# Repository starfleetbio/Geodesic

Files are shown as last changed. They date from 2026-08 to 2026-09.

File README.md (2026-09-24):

# Magnetic Geodesic Dome — Scale Model

A 3D-printed, magnet-assembled scale model of a geodesic dome (Montreal Biosphère–inspired),
built as a proof-of-concept for an eventual larger structure. The rest of this page is the
build spec; first, the short version of how it comes together.

<p align="center">
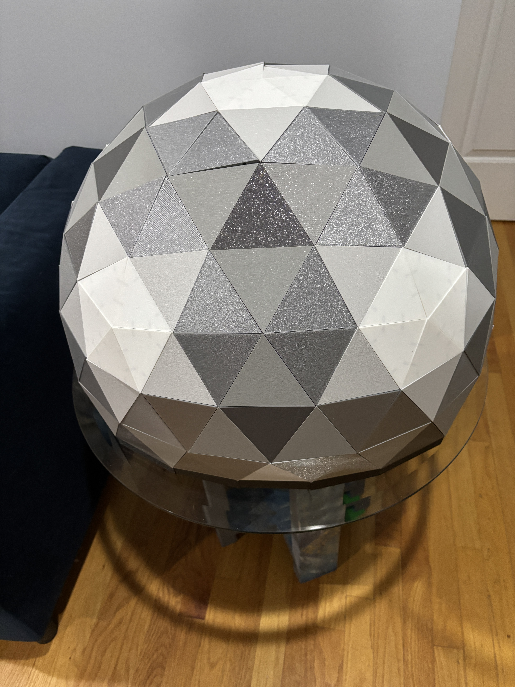
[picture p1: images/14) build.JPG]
The finished dome — 200 panels on a black arc rim, grey ramp from light vertices to dark face centers
  
  <br><em>The built dome — 200 panels seated on the 20-piece black arc rim, greys running light at the vertices to dark at the face centers.</em>
</p>

## From a sphere to a dome you can hold

Geodesic domes turn a sphere into a lattice of triangles — the geometry behind landmarks like Montreal's
**Biosphère** and EPCOT's **Spaceship Earth**, and the starting point for this model.
(Background: [Geodesic polyhedron — Wikipedia](https://en.wikipedia.org/wiki/Geodesic_polyhedron).)

<p align="center">
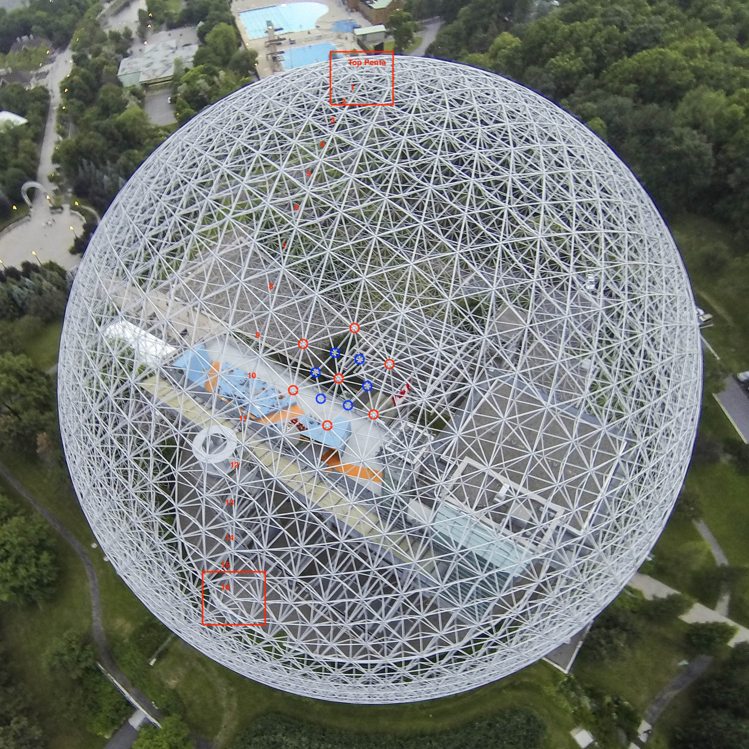
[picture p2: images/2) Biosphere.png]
Montreal Biosphère
  
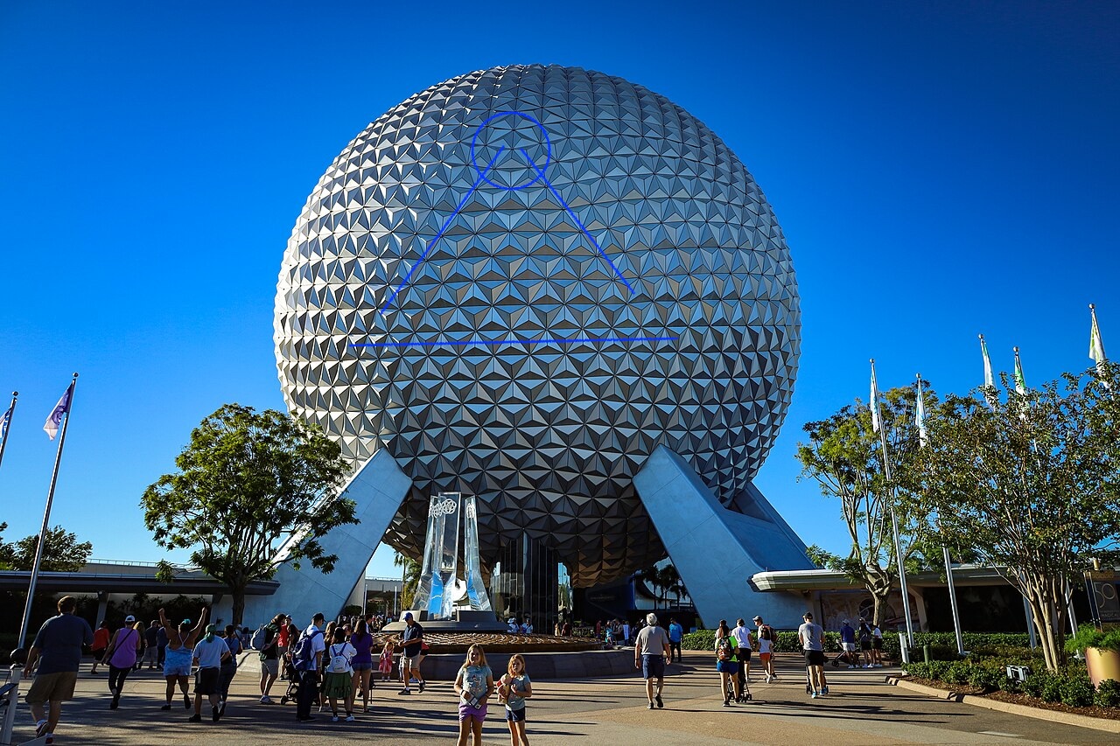
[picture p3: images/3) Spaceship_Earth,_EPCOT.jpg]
Spaceship Earth, EPCOT
  
</p>

<p align="center">
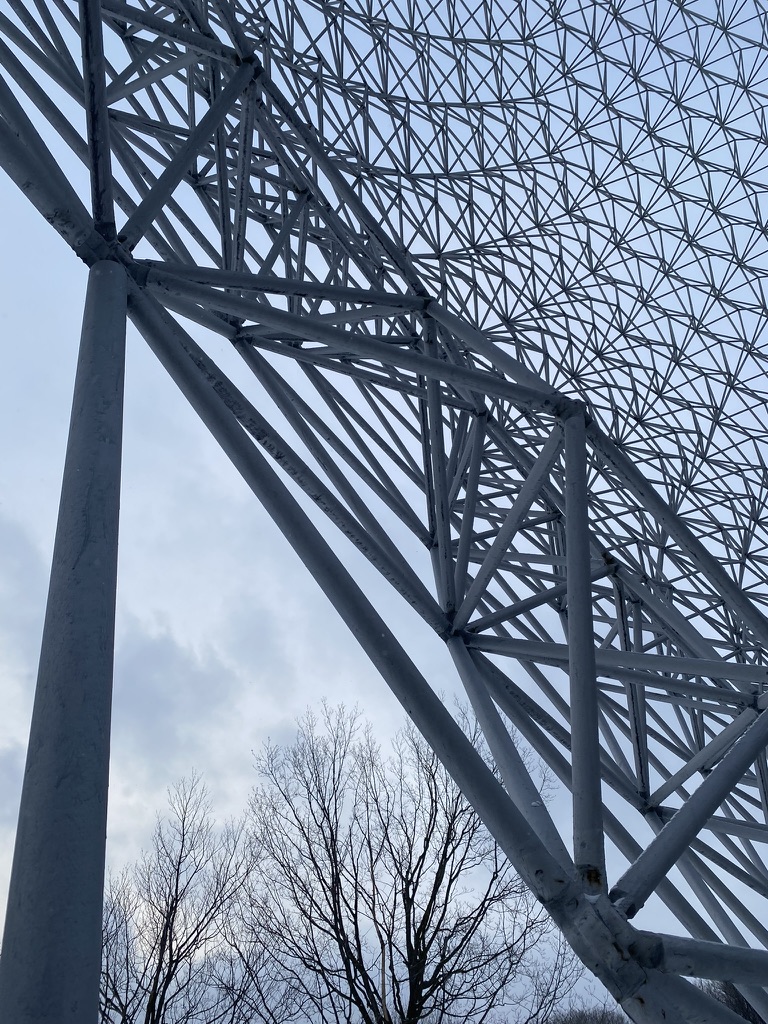
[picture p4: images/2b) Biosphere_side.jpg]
Side view of the Montreal Biosphère geodesic frame
  
  <br><em>A side view of the Montreal Biosphère — the geodesic frame up close.</em>
</p>

Start with an icosahedron and subdivide each of its 20 triangular faces into a finer grid — here **4V**
(four divisions per edge), giving 16 small triangles per face in just five distinct shapes.

<p align="center">
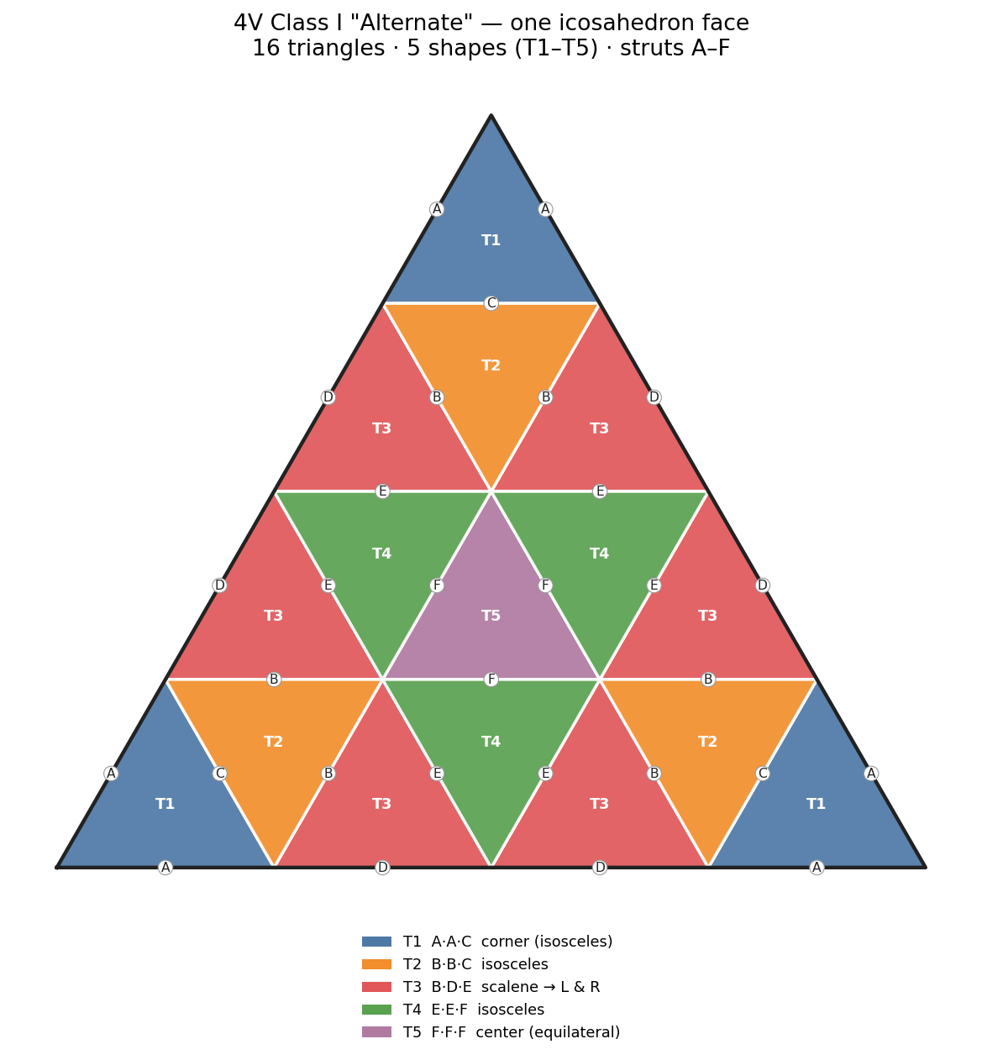
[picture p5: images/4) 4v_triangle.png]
One face subdivided 4V into 16 triangles, shapes T1–T5
  
</p>

Do that to all 20 faces and the whole sphere unfolds into this net:

<p align="center">
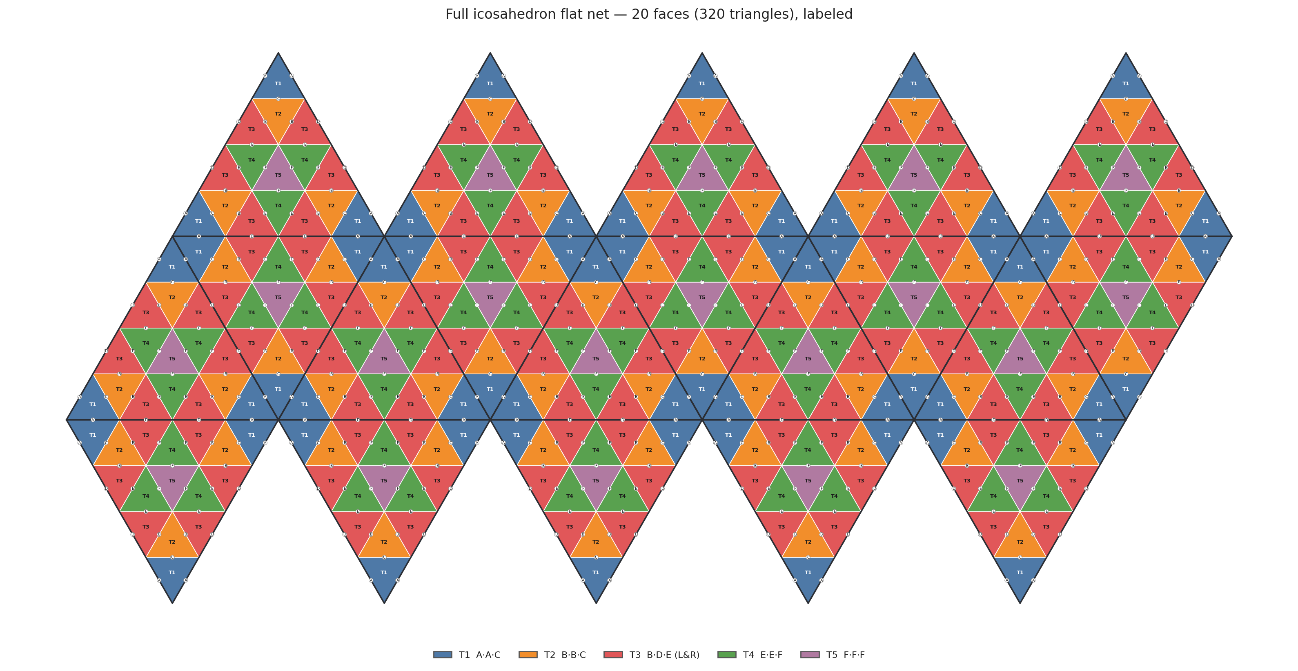
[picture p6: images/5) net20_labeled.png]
Full icosahedron flat net — all 20 faces
  
</p>

A full sphere isn't a dome, though — you cut it. Different fractions give different domes:

<p align="center">
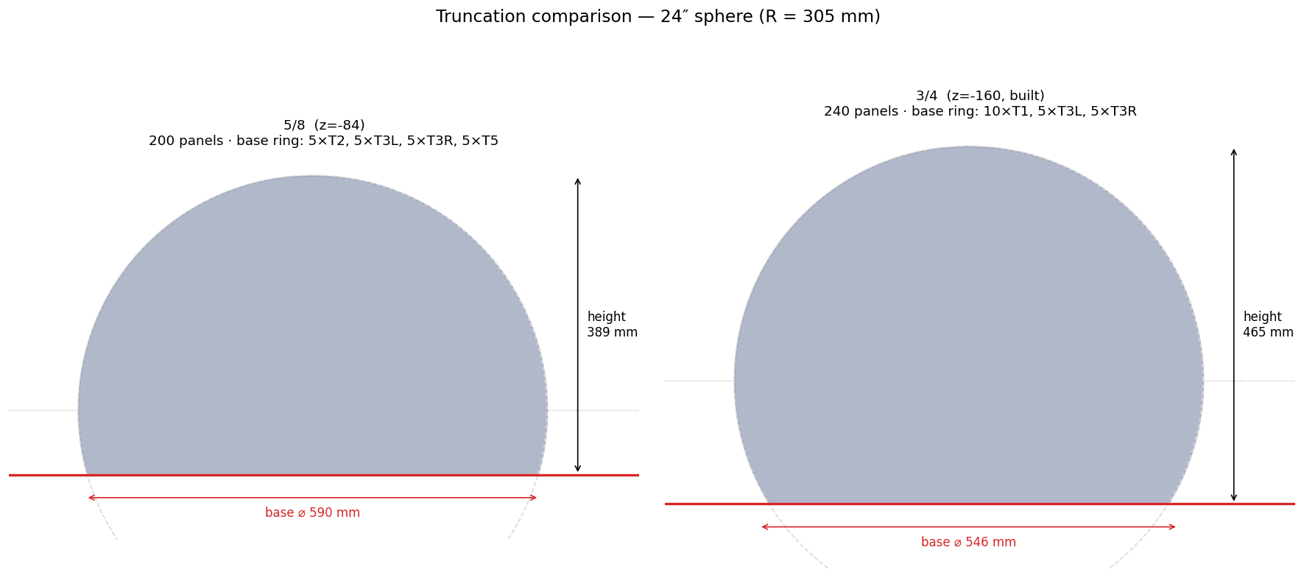
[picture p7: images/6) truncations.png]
Truncation options for the sphere
  
</p>

This model takes the **5/8** cut — everything above a plane just below the equator. That leaves **200
panels**: the actual dome, unfolded (inside view) and colored by shape:

<p align="center">
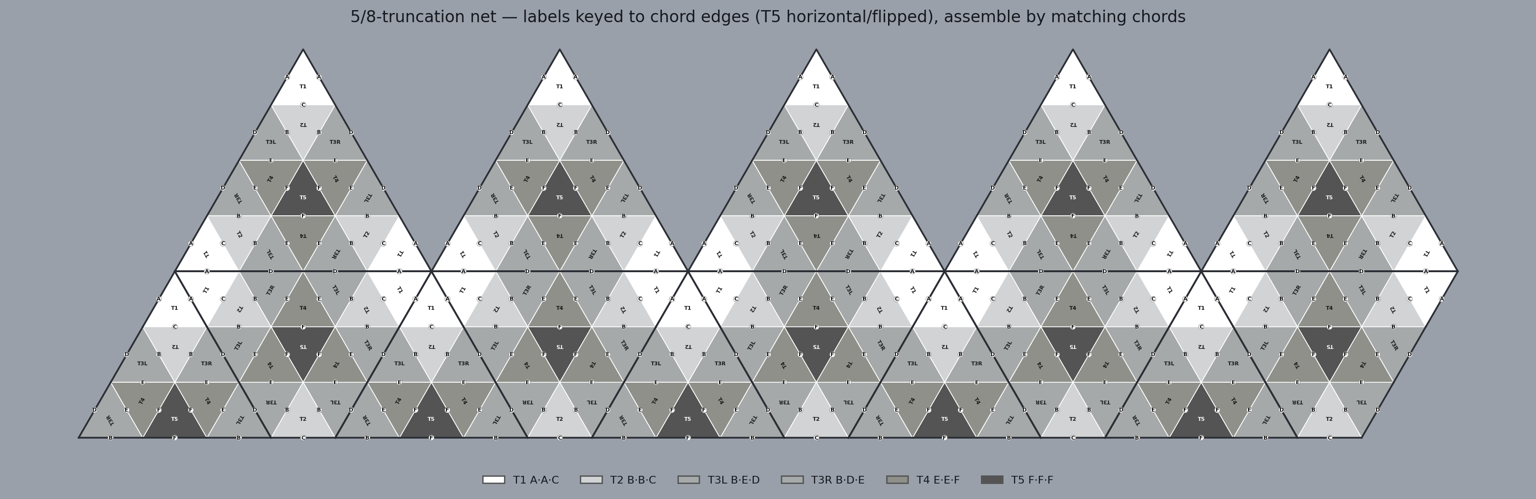
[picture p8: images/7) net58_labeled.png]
5/8-truncation flat net — 200 panels
  
</p>

Those 200 panels reduce to just **six printable parts** (T3 is chiral, so left and right):

<p align="center">
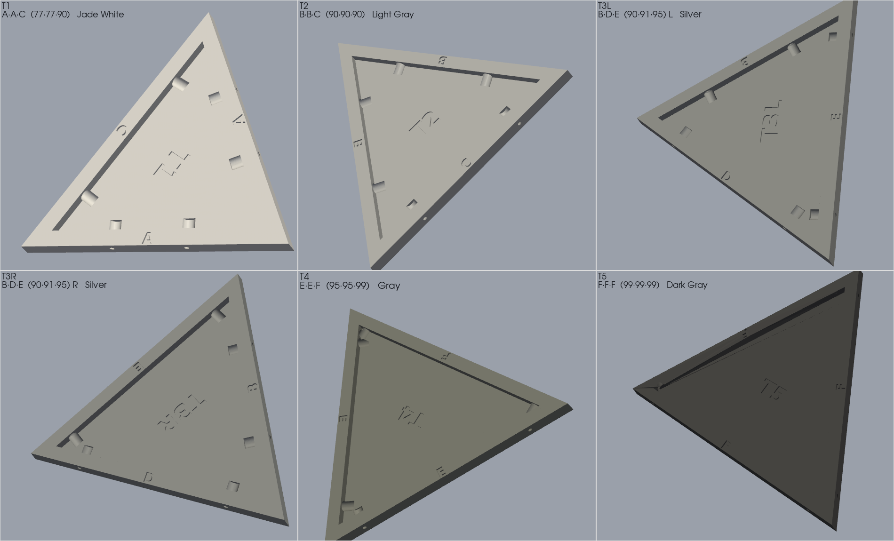
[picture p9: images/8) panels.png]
The six panel shapes, inner face up with labels
  
</p>

Give each shape its own grey — light at the vertices, dark at the centers — and the finished dome reads its
own structure, floating on a black base ring:

<p align="center">
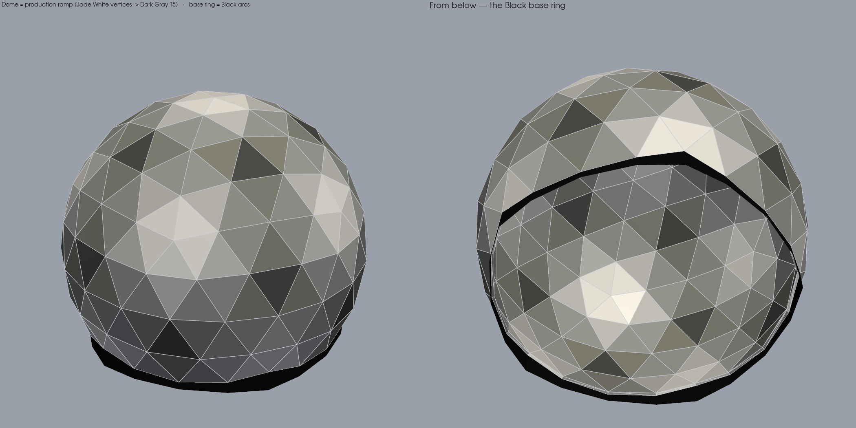
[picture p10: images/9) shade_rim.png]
Dome rendered in the production color ramp
  
</p>

That base is **20 pieces in 4 shapes** T3R(B), T5(F), T3L(B), T2(C) that mitre together into the rim — read them as several arcs or as one continuous ring:

<p align="center">
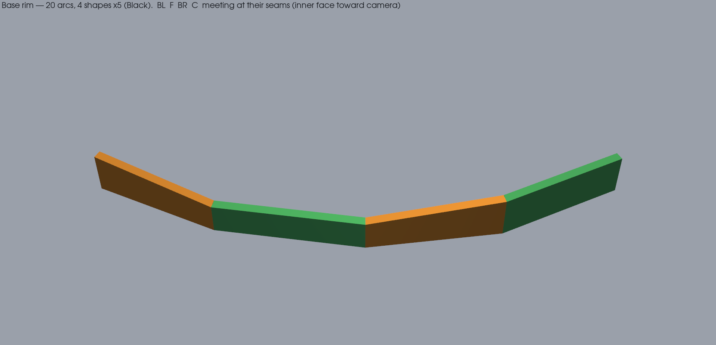
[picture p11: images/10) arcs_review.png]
The four rim arc shapes in black
  
</p>

Everything holds together with **magnets, not glue**. Each edge is *keyed* — its magnet pair sits at a
spacing unique to that chord — so only the correct panels can mate:

<p align="center">
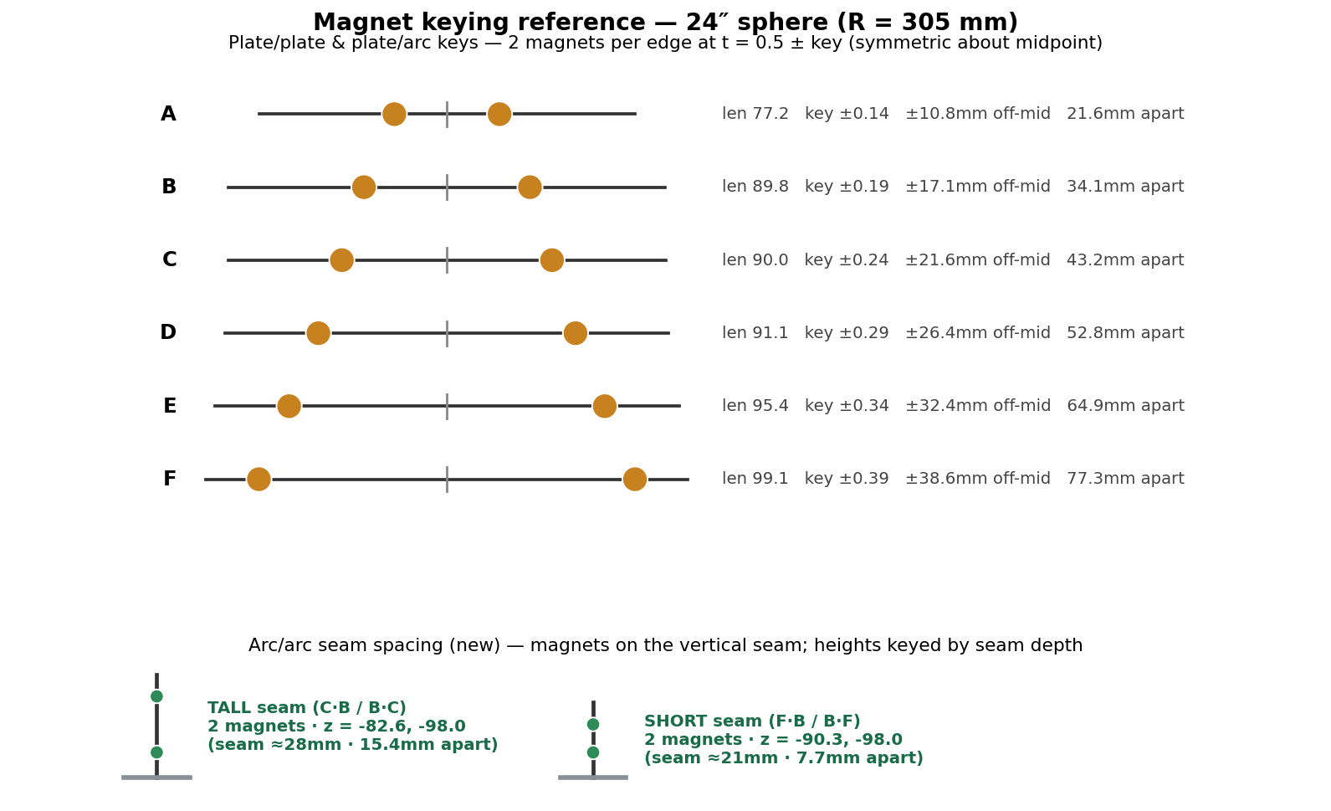
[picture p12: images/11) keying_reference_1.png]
Magnet keying reference
  
</p>

And every magnet lives in the same little channel: a spherical seat that holds the ball flush at the surface,
a short throat that captures it, and a slide to load it from behind with a tamper:

<p align="center">
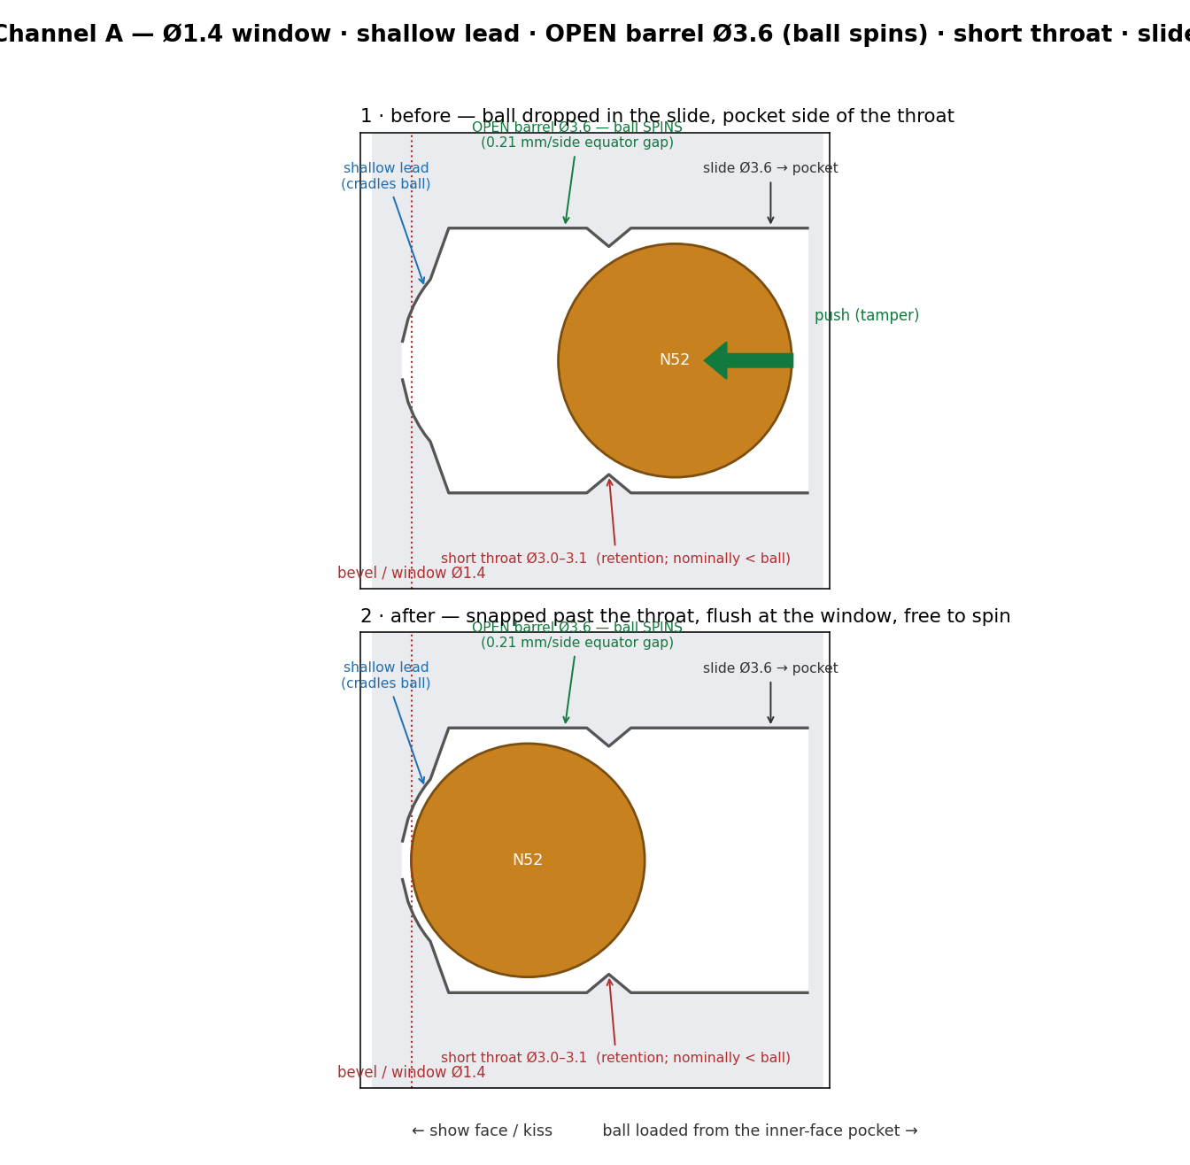
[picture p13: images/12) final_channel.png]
Magnet channel cross-section
  
</p>

---

# Spec sheet

*Rev. after first test print: tapered channel (prints open), show-face-flush orientation (no tilt),
thicker arc walls, bigger/deeper labels. See "First-print revisions" at the end.*

---

## Geometry

| | |
|---|---|
| Solid | Icosahedron |
| Subdivision | **4V (frequency 4)**, **Class I, Method 1** ("alternate") |
| Sphere diameter | **24 in (610 mm)** — radius R = 305 mm |
| Truncation | **5/8** (vertex-up, cut just below the equator at z ≈ −84 mm) |
| Dome height | ≈ 389 mm |
| Base diameter | ≈ 590 mm (a 20-sided zig-zag, amplitude only 7.7 mm) |

The base chord cycle repeats **C · B · F · B** (panels **T2 · T3 · T5 · T3**) five times around.

---

## Panels — 200 total, 6 printable shapes

| Shape | Chords | Edge lengths (mm) | Count |
|---|---|---|---|
| **T1** | A·A·C | 77.2 · 77.2 · 90.0 | 30 |
| **T2** | B·B·C | 89.8 · 89.8 · 90.0 | 35 |
| **T3-L** | D·B·E | 91.1 · 89.8 · 95.4 | 40 |
| **T3-R** | B·D·E | 89.8 · 91.1 · 95.4 | 40 |
| **T4** | E·E·F | 95.4 · 95.4 · 99.1 | 40 |
| **T5** | F·F·F | 99.1 · 99.1 · 99.1 | 15 |

Chord factors → mm (× R = 305): **A 77.2 · B 89.8 · C 90.0 · D 91.1 · E 95.4 · F 99.1**

Each panel: thin central **web 2.2 mm**, thicker **magnet rim 5.2 mm**, edges beveled along the
sphere's radial rays so they close into a sphere. Printed **outer-face-down** for a glossy exterior.

---

## Part labels (debossed on the inner face)

So panels can be sorted and oriented at assembly, each carries ID marks **debossed 0.6 mm into the
inner (pocket) face** — hidden on the finished dome, and facing up during printing so they engrave
cleanly with no supports. The outer show face is untouched.

- **Shape name** (T1 / T2 / T3L / T3R / T4 / T5) centered on the web, upright along the longest edge.
- **Chord letter** (A–F) centered on the rim band beside each edge, so the mating chord is obvious.
- **Arcs** carry their two seat chords: the T2·T3 arc reads **C** and **B**; the T5·T3 arc reads **F** and **B**.

---

## Rim — 20 arcs, 4 printable shapes  *(redesigned: arcs are now built as panels)*

The base ring was reworked so the arcs are **constructed and printed exactly like the triangular panels** —
flat, show-face-down, with the identical channel A loaded from the inner face. This replaced the old two-edge
arcs that printed standing up and whose magnets could not be inserted at all. Each old arc is split at its
middle vertex into two single-chord pieces, giving **20 arcs in 4 unique shapes, 5 each**:

- **C** — top chord C (seats a **T2**); two *tall* seams (symmetric)
- **F** — top chord F (seats a **T5**); two *short* seams (symmetric)
- **BL / BR** — top chord B (seats a **T3-L / T3-R**); one tall + one short seam (mirror pair)

Around the ring the chords run **B F B C** (×5). The seam heights — **tall ≈28 mm** at the C/B vertices,
**short ≈21 mm** at the F/B vertices — key the BL/BR mirror pair automatically: a tall seam only closes
against a tall seam, so a piece can't seat in its mirror's slot.

Construction (same helper as `build_panel`): a **radial frustum** (outer on the sphere at R, inner at
R−t_rim) so every edge is **beveled for free** at the panel dihedral; a **t_web pocket** on the inner face;
**channel A** cut on the top chord (to the panel above) and on both seams (to the neighbor arcs), **all loaded
from the inner face**. Wall thickness is the panel's **t_rim = 5.2 mm** (radial), pocket depth t_rim−t_web =
**3.0 mm** — byte-identical to a panel, so channel A sits at the same depth (Ø3.6 slide at 2.6 mm, 0.80 mm
wall over each magnet). The floor was dropped to **z = −105** so the short seams fit two magnets. Seam
magnets: **2 per seam** — the −105 floor makes even the short seams (~21 mm) tall enough for two (lower magnet
7 mm above the floor on every seam; tall pair 15.4 mm apart, short pair 7.7 mm apart).

Verified against the existing panels, all deltas **0.000 mm**: arc top-edge magnet windows coincide with the
owning panel's (C→T2, F→T5, BL/BR→T3-L/R); adjacent-arc seam windows coincide; and the arc∩panel and arc∩arc
*solids* abut with **zero interpenetration** (seam miters use the tangential bisector plane; a full-panel-plane
top cut was rejected — it sliced the wall into a wedge). Chord letters are debossed at the panel size (4.5/0.8).

---

## Magnets — 1/8 in (3.175 mm) N52 neodymium spheres

- **2 per edge**, free to rotate in their sockets to self-align polarity.
- Total = **1,320 magnets** (200 panels × 6 = 1,200 in panel edges; 20 arc pieces × 6 = 120 in arcs).
- Force is not the constraint — a single pair vastly exceeds the model's hoop tension; the sphere shape
  lets each ball find its own polarity.

### The one channel (identical for every magnet)

```
Ø1.4 window ← shallow spherical lead → OPEN barrel Ø3.6 → short chamfered throat Ø3.0 → slide Ø3.60 (to perimeter + 3.6 mm)
```

The channel axis is straight (one revolve, so no boolean-junction faces). One axis works because the kiss
direction (out the bevel) and the load direction (in from the pocket) are only ~5° apart on this
shallow-dihedral dome. **This is channel "A", locked by the coupon-2 magnet test** (see below); it replaced
a full Ø3.45 spherical cup that seated the ball beautifully but gripped it so hard it would not rotate.

- **Ø1.4 window (flush datum)** — the bevel truncates the seat to a Ø1.4 hole (1.4 < 3.175, so the ball can't
  escape the front). The ball floats forward to the window and, at assembly, the two mating **bevels close
  face-to-face** — *that* is what sets the flush kiss (front ~0.01 mm proud, so neighbor magnets touch). Because
  the kiss is set at the window/bevel, everything behind the window can be opened up for rotation **without
  changing how panels mate** — new parts kiss at the identical point as every part already printed.
- **Shallow spherical lead** — a short concentric spherical arc just behind the window cradles the ball
  forward (this is what gives retention its margin), *without* wrapping its whole front hemisphere the way the
  old full cup did. In the coupon test the two shallow-seat cases (A, B) both spun **and** retained; the cone
  seat (D) lost the ball out the throat because it had no forward cradle. So: shallow lead, not cone.
- **Open barrel Ø3.6** — behind the lead the ball's equator runs in a cylinder **0.21 mm wider per side** than
  the ball, so it **spins freely to self-align polarity**. This was the whole fix: opening the barrel (not
  touching the throat) is what freed rotation. Ø3.6 was chosen over Ø3.7/3.8 for the tighter retention margin
  and the thicker wall over the magnet (**0.80 mm** vs 0.70 mm at Ø3.8).
- **Throat = the retention knob (barrel/seat = A; throat is separate).** Coupon-2's letters A–F only varied
  barrel/seat at a *fixed* Ø3.2 throat, so "A" means **barrel Ø3.6 + shallow seat** and says nothing about the
  throat. Ø3.2 is only 0.025 mm under the 3.175 ball, so it captures **only** via the printer's ~0.1 mm shrink —
  which held on panels but **let the ball fall out of the arcs**. **Now locked** at **Ø3.0 on panels and arc
  top chords, Ø3.1 on arc-to-arc seams** (nominally under the ball → captures by geometry, not luck); this is
  what the shipped STLs use (`scripts/build_final_panels.py`, `scripts/build_arc_run.py`). Barrel/seat stay
  at A. Throat affects rotation not at all — purely capture.
- **Slide Ø3.60** — runs from the throat to the **perimeter** then **3.6 mm into the pocket** — just enough
  to drop the ball in and start a tamper rod straight.

*(Arc seat/splice magnets share the same window/kiss datum; the panel channel A geometry now applies to them
too, so panel and arc sockets are unified.)*

### How magnets are loaded (post-print, printer OFF)

Drop the ball into the slide from the pocket side, then push it with a small blunt rod (a **tamper**,
~2.5–3 mm) through the neck until it snaps into the socket flush at the window. The slide is the tamper's
guide. **Both panels and arcs load the same way — from the inner-face pocket, perpendicular to the edge** (the
arc redesign unified this; there is no separate "load up from the floor" case anymore).

### Keys (so wrong edges never mate)

Two magnets per edge at **t = 0.5 ± key**, symmetric about the midpoint, distinct per chord:

| A | B | C | D | E | F |
|---|---|---|---|---|---|
| ±0.14 | ±0.19 | ±0.24 | ±0.29 | ±0.34 | ±0.39 |

→ 21.6 mm apart on A edges, widening to 77.3 mm on F edges.

Splice keys: **3 magnets** stacked up the tall (T2·T3↔T5·T3) joints, **2** up the short
(T5·T3↔T2·T3) joints, ~7.7 mm apart, from 4 mm above the floor to 4 mm below the top.

---

## The coupons — how channel "A" was dialed in *(resolved)*

The fit that captures-and-holds while still letting the ball **spin** can't be predicted (the interference is
smaller than a 0.4 mm nozzle's ±0.1–0.15 mm repeatability), so it was measured on the machine with two
throwaway **coupons** — small test blocks, each a real T1 panel with the live channel repeated 6×,
printed show-face-down like a real panel.

- **Coupon 1 — throat sweep** (2.9 / 3.0 / 3.1 / 3.2 / 3.3 mm). Result: every throat captured and held, but
  **none let the ball rotate** — proving the throat was *not* what jammed rotation. The culprit was the full
  spherical cup gripping the ball's whole front hemisphere.
- **Coupon 2 — seat/barrel sweep** (throat fixed 3.2, window fixed 1.4; barrel Ø3.6/3.7/3.8 × shallow-seat vs
  cone vs the old full cup). Result: **A (barrel 3.6, shallow seat) and B (3.7, shallow) both spun and
  retained**; the cone (D) spun but **lost retention**; the old full cup (F) was too tight to rotate. **A won**
  — it rotates, has the best retention margin, and the thickest wall over the magnet. (Ø3.8 cases were void:
  the wide barrel reached the rim and the label deboss cut into the bore.)

**Outcome:** channel A is now the library default for every panel and arc, and the throat is locked at
**Ø3.0 (panels + arc top chords) / Ø3.1 (arc seams)** — see the *Throat = the retention knob* bullet above.
Nothing further to dial in.

Shortcut if you don't want a separate coupon: **print your face test plate at neck 3.10 and use it as both
the coupon and your first real face.** If 3.10 is too tight or too loose once magnets arrive, it's a
one-line change and a reprint, with a real target to aim at.

Even with no magnets on hand yet, the first plate confirms everything that *doesn't* depend on them: flat
release, clean bevel dry-fit, readable labels, brim/first-layer behavior on the thin rim, and crisp slide
openings and windows.

---

## Colors (production)

The model is assembled **one color at a time** (single-extruder P1S), and color is made to carry the
shape information — so the finished dome reads as a graded pattern *and* the loose parts stay sortable by eye.

**Panels — a 5-step grey ramp, light at the vertices → dark at the centers.** Each of the five panel
shapes gets its own tone: lightest on **T1** (the little triangles clustered at the icosahedral vertices),
darkening step by step to **charcoal on T5** (the equilateral panels at each face center). This makes the
geodesic structure legible — the pentagonal vertex "stars" read light against dark face-centers — and
doubles as a bench sort key.

| Shape | Target tone (hex) | Bambu PLA Basic | Where it sits on the dome |
|---|---|---|---|
| **T1** | near-white `#F7F7FA` | **Jade White** `#FFFFFF` | vertex clusters |
| **T2** | light grey `#CCD1DB` | **Light Gray** `#D1D3D5` | just around the vertices |
| **T3-L / T3-R** | mid grey `#9EA3B0` (**shared**) | **Silver** `#A6A9AA` | the connective band |
| **T4** | dark grey `#737887` | **Gray** `#8E9089` (or Blue Grey `#5B6579`) | toward the face centers |
| **T5** | charcoal `#474C5C` | **Dark Gray** `#545454` | face centers |
| **Arcs (×20)** | — | **Black** `#000000` (its own "ground" tone) | base rim |

Bambu-color matches are nearest-hex from their official [PLA Basic hex table](https://store.bblcdn.com/s7/default/1084369ef84345bbaa5d704a492954e0/Bambu_PLA_Basic_Hex_Code.pdf);
T1/T2/T3/T5 are near-exact, T4 is a toss-up between **Gray** (better value separation) and **Blue Grey**
(truer to the cool tint). Confirm against a physical swatch before buying — printed PLA never matches an
on-screen hex.

The ramp is a **cool grey** (a faint blue in the neutral), stepping evenly white→charcoal. These are the
design-intent tones from the dome render (`shades2.py`); an earlier alternate ramp ran slightly lighter and
warmer (`shades.py`: `#F2F5FA · #D4D9E3 · #ADB5C2 · #858C9C · #596170`) if you prefer more contrast at the
dark end.

**T3-L and T3-R share one tone.** They're mirror images, so a single mid-grey covers both — the magnets'
keying (distinct per chord) enforces the chirality at assembly, so color doesn't have to. That keeps the
ramp to **five** filaments, not six.

**Arcs — Black (a sixth, "ground" color).** The 20 base rim arc pieces print in **Black** — a step below even the
T5 charcoal — so the base is its own element, not borrowed panel-grey. The five greys *code the five panel
shapes*; black reads as "not a panel, the ground the dome sits on." It gives a crisp value break wherever the
base meets the dome (even the darkest T5 panels stay distinct from the rim), recedes to pure shadow so the
grey dome floats above it, and completes the palette as an even six-step scale (White → Light Gray → Silver →
Gray → Dark Gray → Black). Black is also the cheapest, most consistent filament and hides ground scuffs best.
*Caveat:* pure black shows geometry (layer lines, blemishes catch light more than on grey), so the arcs want
clean first layers. (For a bright, deliberate plinth instead, **Jade White** arcs are a drop-in swap; to stay
at five spools, share the arcs onto **Dark Gray** with the T5 panels.)

The hex are **targets**, not exact filament colors — printed PLA won't land on a hex, so treat the Bambu
column as the nearest match and confirm on a swatch. (Prototyping is being done in the P1S sample **green** —
just a working color, not part of the scheme.)

### Filament quantities (full dome — 200 panels + 20 arc pieces)

Printed masses are calibrated from a real slice (the 117.06 g face plate → **0.906 g/cm³** effective, which
already includes walls + infill), so these are build numbers, not solid-volume guesses.

Per part, printed: **T1 ≈ 8.0 g · T2 ≈ 9.6 g · T3-L/R ≈ 10.0 g · T4 ≈ 10.9 g · T5 ≈ 11.3 g**; arc pieces
≈ **10–12 g** each (each old T2·T3 / T5·T3 arc is now split at its middle vertex into two halves).

Per color for the whole dome — net, and with a **+15 %** allowance for brim, purge, and the odd failed part:

| Color (Bambu) | Covers | Net | +15 % | 1 kg spools |
|---|---|---|---|---|
| **Jade White** | T1 ×30 | 240 g | 276 g | 1 |
| **Light Gray** | T2 ×35 | 336 g | 387 g | 1 |
| **Silver** | T3-L ×40 + T3-R ×40 | 800 g | 920 g | 1 |
| **Gray** (T4) | T4 ×40 | 436 g | 501 g | 1 |
| **Dark Gray** | T5 ×15 | 169 g | 195 g | 1 |
| **Black** | arc pieces ×20 | 215 g | 247 g | 1 |
| **Total** | 200 panels + 20 arc pieces | **2196 g** | **2525 g** | **6** |

Six colors, one 1 kg spool each — **~2.5 kg with margin**. The black is the lightest lift: the 20 arc pieces need
only ~215 g, so a single spool covers them several times over (and black is the cheapest, most available
stock). To collapse back to **five** spools instead, share the arcs onto **Dark Gray** with the T5 panels
(Dark Gray → ~442 g, still one spool).

### Plates to print (full dome, from scratch)

Per-plate capacities are measured from the production 3MF plates. Rounding each shape up to whole plates
gives the plate count for building the entire dome from nothing:

| Type | Color | Need | Per plate | Plates | Yields | Spare |
|---|---|---|---|---|---|---|
| **T1** | Jade White | 30 | 14 | 3 | 42 | 12 |
| **T2** | Light Gray | 35 | 12 | 3 | 36 | 1 |
| **T3-L** | Silver | 40 | 12 | 4 | 48 | 8 |
| **T3-R** | Silver | 40 | 12 | 4 | 48 | 8 |
| **T4** | Gray | 40 | 10 | 4 | 40 | 0 |
| **T5** | Dark Gray | 15 | 9 | 2 | 18 | 3 |
| **Arcs** | Black | 20 | 20 | 1 | 20 | 0 |
| **Total** | | **220** | | **21** | **252** | **32** |

**21 plates** total — 20 panel plates plus the single 20-up arc plate — yielding 252 pieces for the 220
needed, leaving 32 spares. At ~6 h per plate that is **~126 h** of print time, roughly 5–6 days
near-continuous. **Silver is the long pole at 8 plates** (4 T3-L + 4 T3-R). Two plates are **zero-margin**:
**T4** (4 plates = exactly 40) and the **arc plate** (exactly 20), so a single failure in either forces a
partial reprint — add a 5th T4 plate if you want a safety margin there.

---

## Production sequence (print & build)

**Build as face modules — this is what fits single-color printing.** The dome is ~**12½ identical face
triangles** plus the base ring. Every face is the same recipe, and every panel of a given color is
interchangeable, so printing (which yields piles of one color at a time) maps straight onto it: sequence
plates for printer efficiency, and assemble faces continuously from bins.

**One face module (16 panels):**

| Color | Panels per face |
|---|---|
| White (T1) | 3 |
| Light Gray (T2) | 3 |
| Silver (T3-L + T3-R) | 6 |
| Gray (T4) | 3 |
| Dark Gray (T5) | 1 |

*(Black arcs aren't part of a face — they're the separate base ring.)*

**Flow:**

<p align="center">
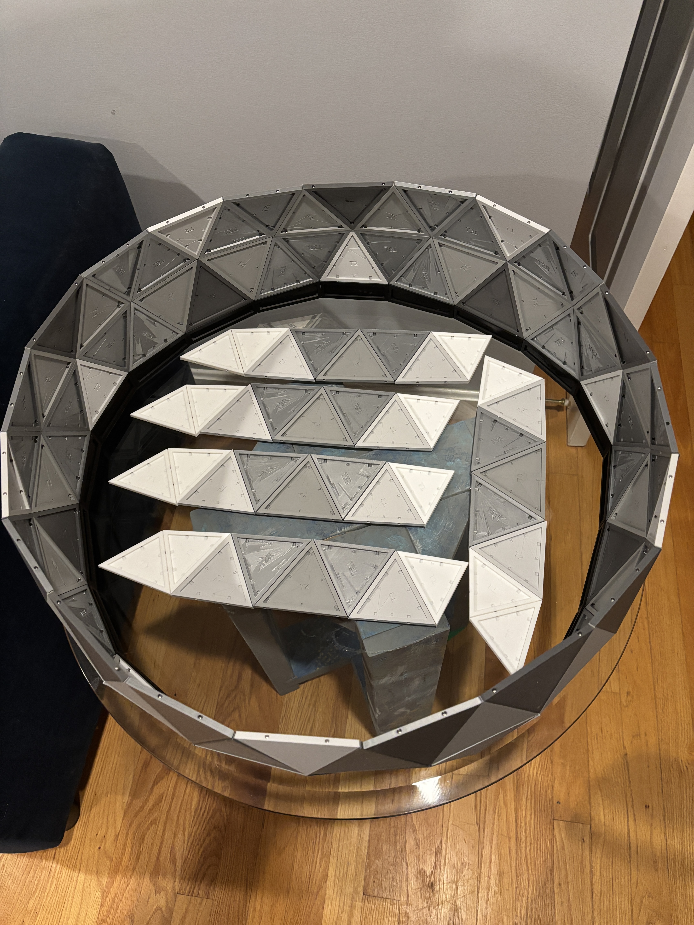
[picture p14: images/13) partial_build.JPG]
The build in progress — black arc ring closed, dome partially assembled on it, remaining face modules laid out beside
  
  <br><em>The flow in progress: black rim closed first, a band of the dome seated on it, remaining face modules pre-assembled off to the side and waiting to dock.</em>
</p>

1. **Base first.** Print the 20 Black arc pieces (~5 h) and assemble the mitred base ring — the foundation faces dock onto.
2. **Silver is the pacing color** — 6 of every 16 panels, 80 total. Keep Silver printing more or less
   continuously in the background; face completion is gated by how fast Silver arrives.
3. Print the four accent colors (White, Light Gray, Gray, Dark Gray) in **full single-color plates** around
   the Silver, changing filament only at plate boundaries (finish a color before switching to keep swaps low
   — ~19 color loads total across the run).
4. **Assemble a face** whenever the bins hold a full set (3 White · 3 Light Gray · 6 Silver · 3 Gray ·
   1 Dark Gray): drop and tamper its two magnets per edge, key-checked, then set the finished triangle aside.
5. **Dock faces bottom-up** onto the base ring, closing each horizontal course as a self-supporting
   compression hoop, up to the top cap.

This decouples printing from assembly: a failed panel is a non-event (pull the next same-color part from the
bin), and the printer never waits on the assembler or vice-versa.

*Alternative — progressive rings ("arcs up").* To watch a freestanding dome rise instead of building
modules, print bottom-up by course: the surface is **17 courses**, grouped into a base ring + ~6
color-interleaved phases (widest belt → equator → … → top cap), assembling each ring as its colors finish.
Same final result; it just couples print order to assembly order (more, smaller color batches) in exchange
for a taller dome after every phase.

**Scale:** ~**200 panels + 20 arc pieces** across **21 plates** (20 panel + 1 arc) at measured per-plate
capacities — see **Plates to print** above. At ~6 h per plate that is ~**126 h** of printing (more with
reprints), six PLA Basic spools (~2.5 kg). Silver is the long pole at 8 plates; the top third goes quickly.

---

## Print settings (Bambu P1S, 256 mm bed, 0.4 mm nozzle, one color at a time)

Standard:

- **Outer-face-down**, **supports OFF**, elephant's-foot compensation ~0.15 mm.
- Do **not** auto-orient / "place on face" — parts are pre-flattened show-face-down and just Auto-arrange.
- Full face (16 panels + 4 arc pieces) ≈ 3 plates.

For rounder holes and a crisper neck (the channels print as horizontal holes, whose tops tend to sag):

- **Layer height 0.16 mm** for panels (**0.12 mm** for the coupon) — thinner layers round the horizontal holes.
- **Calibrate flow rate / extrusion multiplier first** — over-extrusion is what closes small holes and tightens the neck.
- **Calibrate pressure advance** — keeps hole edges sharp instead of bulged.
- **Slow the outer wall / small-perimeter speed** (~50–100 mm/s) so the channel walls lay down cleanly.
- If slicing in **OrcaSlicer**, enable **X-Y hole compensation** to counter the typical hole under-sizing
  (Bambu Studio lacks a direct equivalent — lean on flow calibration there).
- The Ø1.4 window will likely print slightly under — that only *improves* retention, so it's fine.

**Bambu Studio process settings** (the exact toggles, plus what the first prints taught us):

- **Brim type: Auto** — *not* a forced "Outer brim." These are wide flat parts with a thick perimeter, so
  Auto adds none (huge bed-contact patch, no brim needed). A forced brim only mars the show-face edge and is
  annoying to peel. If a sharp triangle *tip* ever lifts, use **Mouse ears** (tiny corner discs), not a full brim.
- **Ironing → type: "Top surfaces."** Smooths the hidden inner face (the streaky top-skin we saw); optional, adds time.
- **Top surface pattern: Monotonic**, **Top shell layers: 4–5** — a fully-closed, uniform top skin.
- **Layer height 0.16 mm** for panels (**0.12 mm** for the coupon) — rounds the horizontal magnet holes.
- **Outer-wall / small-perimeter speed ~50–100 mm/s** — clean channel walls and crisp windows.
- **Calibrate flow rate + pressure advance first** — over-extrusion is what closes the small holes / tightens the neck.
- **Bed adhesion (anti-warp):** wash the plate with dish soap + warm water regularly, never touch the print area
  with bare fingers, and keep the **large flat panels toward the plate center** (the cooler edges are where big
  flats lift). Keep the door/lid closed. *(A T4 warped-and-rippled on plate 2 — it was a first-layer adhesion
  failure at a plate edge, not a lack of brim.)*
- **Orientation is baked in:** every part is pre-flattened **show-face-down** via the deterministic
  "largest-coplanar-facet → bed" method, **verified 0.000° tilt**. Do not re-orient — a residual tilt of only
  ~0.2° prints the first layer in visible steps (the T4/T5 files had this before the fix). Just Auto-arrange.
- **Save ONE process preset and slice every plate from it.** Plate-to-plate drift in settings is what let T4/T5
  come out tilted while the rest were flat; a single locked preset keeps all 200 panels identical.

Color scheme: see **Colors (production)** above — a 5-step Bambu grey ramp by shape (Jade White T1 → Dark
Gray T5, T3-L/R share Silver) plus **Black** for the base arcs. Six PLA Basic spools, ~2.5 kg total. Print
one color at a time.

---

## Repository layout

Print-ready files sit at the top of the repo; test iterations and superseded parts are archived under `tests/`.

- **`3mf/`** — production Bambu Studio plates, one file per color. `T1_JADE`, `T2_LT_GR`, `T3L_T3R_SILVER` (both mirror shapes on one Silver plate — they share the color), `T4_GR`, `T5_DK_GR`, `Arc_BLK`. A trailing `_NX` on a filename is a reminder of how many plates to print (`_1X` = one plate, `_2X+` = two-or-more). A local `3mf/maybe/` (gitignored) may hold alternate plate layouts of the same STLs pending review — not part of the checked-in kit.
- **`stl/`** — bare geometry, one file per shape. `T1`–`T5` (T3L / T3R split) plus `arc_T2` / `arc_T3L` / `arc_T3R` / `arc_T5`.
- **`scripts/`** — generators for `stl/` and the net image, plus `requirements.txt` pinning the exact Python library set they were built against. See **Reproducing the STLs** below.
- **`Dockerfile`** + **`scripts/docker-entrypoint.sh`** — reproducible build image so anyone can verify the checked-in `stl/` came from the scripts, or regenerate them into their own tree.
- **`tests/dev/`** — chronological test-print folders (`Test_1_Panels` through `Test_7_Panels`).
- **`tests/stl/`** and **`tests/3mf/`** — earlier per-shape STLs and 3MFs kept for reference; superseded by `stl/` and `3mf/`. The `tests/stl/{outdated, less outdated}/` piles are the pre-final STLs from while the magnet throat was being dialed in on coupons.
- **`images/`** — the figures used above.

### Reproducing the STLs

The `stl/` files are exactly what was printed and tested. To confirm they come from the scripts in `scripts/`, run the reproducible build image:

```sh
docker build -t geodesic-build .
docker run --rm geodesic-build            # verify: prints a per-file OK/FAIL table
docker run --rm -v "$PWD":/repo geodesic-build build   # regenerate stl/ into the host repo
```

`verify` checks *shape* equivalence, not byte identity: it rebuilds every part inside the container and confirms each is within **100 µm on bounding box** and **1 % on volume** of what's on disk — tolerances well below any FDM printer's resolution. Bit-identity across environments is not a meaningful guarantee (glibc, GCC, and pip-wheel differences shift trailing float bits even at the same package versions), so it's reported as a diagnostic rather than a pass/fail.

Passing run against the current `stl/`:

```text
file           bytes      Δbbox       Δvol result
T1.stl         ≠        0.00 µm   0.000 mm³ OK
T2.stl         ≠        0.00 µm   0.000 mm³ OK
T3L.stl        ≠        0.00 µm   0.000 mm³ OK
T3R.stl        ≠        0.00 µm   0.000 mm³ OK
T4.stl         ≠        0.00 µm   0.000 mm³ OK
T5.stl         ≠        0.00 µm   0.000 mm³ OK
arc_T2.stl     ≠        0.00 µm   0.000 mm³ OK
arc_T3L.stl    ≠        0.00 µm   0.000 mm³ OK
arc_T3R.stl    ≠        0.00 µm   0.000 mm³ OK
arc_T5.stl     ≠        0.00 µm   0.000 mm³ OK

0/10 bit-identical, 10/10 shape-equivalent (Δbbox ≤ 100 µm, Δvol ≤ 1.0%)
```

(The `≠` in the bytes column is expected — my Apple Silicon host runs the amd64 image under Rosetta, whose manifold3d binary orders CSG floats slightly differently than Claude Desktop's native-Linux sandbox. Every mesh is nonetheless geometrically identical to sub-µm precision.)

The image pins Python 3.11 and the exact library versions from `scripts/requirements.txt`. It defaults to `linux/amd64` (matches the sandbox that originally generated `stl/`); on Apple Silicon it runs under Rosetta emulation.

---

## First-print revisions (what the test plate taught us)

The first full-face print worked, and revealed four things — all now fixed in the files:

1. **Stepped neck plugged shut.** The horizontal channel's abrupt slide→neck step sagged closed at the neck.
   → **Tapered channel** (Ø3.6 → Ø3.1 cone), which prints open. Bonus: it also removed a stubborn
   non-manifold edge on the symmetric T5.
2. **Show face printed with a tilted patch.** The old flatten aligned to the panel's average plane (PCA),
   tilting the show face ~0.3° so a corner floated ~0.2 mm off the bed and the first layer was skipped there
   (a crisp triangular texture change). → **Orient on the show face itself**, so it lies dead flat (corner
   spread now 0.000 mm).
3. **Arc seat sockets bled through to a slit** on the inner face (only ~0.8 mm of wall behind them).
   → **7 mm arc wall** (2.6 mm backing now). The *splice* openings on the arc inner face are intentional
   (that's how those end magnets load) and stay.
4. **Chord letters a little hard to read.** → **bigger (4.5 mm) and deeper (0.8 mm)**.

5. **Magnets seated but wouldn't rotate** (found with real magnets, coupon 2). The full Ø3.45 spherical cup
   cradled the ball's whole front hemisphere — great seating, but too much conforming contact to let it spin
   and self-align polarity. → **Channel A**: shallow spherical lead + **open barrel Ø3.6** + throat locked
   at **Ø3.0 (panels + arc tops) / Ø3.1 (arc seams)** (see *The one channel* and *The coupons* above). Balls
   rotate freely and retain; kiss point unchanged, so it mates with every part already printed.

6. **Arcs were wrong in every way and got rebuilt as panels.** The old arcs printed standing up; magnets
   would not insert, edges weren't beveled, and the channels didn't retain.
   → The rim is now **20 flat panel-family arcs in 4 shapes (C, F, BL, BR)** built from the same radial-frustum
   helper as the panels — beveled edges for free, channel A loaded from the inner face, wall = panel t_rim
   (5.2 mm), floor dropped to −105 for two magnets on the short seams. See **Rim** above. Interfaces to the
   existing panels and to neighbor arcs verified exact (0.000 mm). Confirmed on the arc test print and then
   on the full build: rim closes as a self-supporting ring, arc-to-arc seams key correctly, arc-to-panel
   seats seat clean, and the base carries the assembled dome without splay.

### Build outcome

The full **5/8 dome — 200 panels on the 20-piece black rim — is built** (photo at the top of this README).
The spec above is what actually printed and assembled; the two build shots show the face-module flow in
progress and the finished object.

### Resolved (post-build)

- **Throat for retention** — locked. Panels and arc top chords: **Ø3.0**; arc-to-arc seams: **Ø3.1**. Baked
  into the shipped STLs by `scripts/build_final_panels.py` (`throat_d = 3.0`) and `scripts/build_arc_run.py`
  (`top_thr = 3.0`, `seam_thr = 3.1`).
- **Arc-to-panel top seam** — the panel-family dihedral bevel on the arc top edge (`build_arc_run.py`) closes
  the seam by construction; no extra top-edge chamfer needed, and none added.

### Observations from the built dome (worth improving on the next kit)

- **Retention failures roughly 1 in 8 panels, concentrated on T3-L / T3-R (Silver).** About one panel in
  eight had at least one channel that would not hold its magnet. The failure rate was heavily weighted toward
  the Silver panels (T3-L / T3-R), which suggests **the specific Silver filament used here didn't hold channel
  geometry as well as the other Bambu greys** — likely a softer/more slumpy PLA that let the horizontal
  channel walls (and probably the throat) print a hair oversized. Next kit: **try a different silver** (e.g. a
  different brand's silver PLA, or drop back onto a more consistent Bambu grey and re-shade the ramp) before
  changing the geometry. If the same brand is reused, a modest per-color flow calibration for that spool would
  be the first thing to try.
- **T5 panels left a small removable piece of plastic in the channel.** Each T5 needed a small stray piece
  popped out during finishing — most likely an unfused island the slicer left inside the tapered channel on
  T5's specific geometry. Not a functional problem but a real assembly nuisance. Next revision: check the T5
  channel/window/throat interaction (T5 is the equilateral face-center panel, so the three channels meet the
  central web at the tightest angle) and either move the offending detail or accept that T5 wants a slightly
  different slice profile.

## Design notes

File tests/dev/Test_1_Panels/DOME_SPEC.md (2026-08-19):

# Magnetic Geodesic Dome — Scale Model Spec Sheet

A 3D-printed, magnet-assembled scale model of a geodesic dome (Montreal Biosphère–inspired),
built as a proof-of-concept for an eventual full-size welded structure.

*Rev. with shortened slides (perimeter + 3.6 mm), debossed part labels, and print-tuning notes.*

---

## Geometry

| | |
|---|---|
| Solid | Icosahedron |
| Subdivision | **4V (frequency 4)**, **Class I, Method 1** ("alternate") |
| Sphere diameter | **24 in (610 mm)** — radius R = 305 mm |
| Truncation | **5/8** (vertex-up, cut just below the equator at z ≈ −84 mm) |
| Dome height | ≈ 389 mm |
| Base diameter | ≈ 590 mm (a 20-sided zig-zag, amplitude only 7.7 mm) |

The base chord cycle repeats **C · B · F · B** (panels **T2 · T3 · T5 · T3**) five times around.

---

## Panels — 200 total, 6 printable shapes

| Shape | Chords | Edge lengths (mm) | Count |
|---|---|---|---|
| **T1** | A·A·C | 77.2 · 77.2 · 90.0 | 30 |
| **T2** | B·B·C | 89.8 · 89.8 · 90.0 | 35 |
| **T3-L** | B·D·E | 89.8 · 91.1 · 95.4 | 40 |
| **T3-R** | B·D·E | 89.8 · 91.1 · 95.4 | 40 |
| **T4** | E·E·F | 95.4 · 95.4 · 99.1 | 40 |
| **T5** | F·F·F | 99.1 · 99.1 · 99.1 | 15 |

Chord factors → mm (× R = 305): **A 77.2 · B 89.8 · C 90.0 · D 91.1 · E 95.4 · F 99.1**

Each panel: thin central **web 2.2 mm**, thicker **magnet rim 5.2 mm**, edges beveled along the
sphere's radial rays so they close into a sphere. Printed **outer-face-down** for a glossy exterior.

---

## Part labels (debossed on the inner face)

So panels can be sorted and oriented at assembly, each carries ID marks **debossed 0.6 mm into the
inner (pocket) face** — hidden on the finished dome, and facing up during printing so they engrave
cleanly with no supports. The outer show face is untouched.

- **Shape name** (T1 / T2 / T3L / T3R / T4 / T5) centered on the web, upright along the longest edge.
- **Chord letter** (A–F) centered on the rim band beside each edge, so the mating chord is obvious.
- **Arcs** carry their two seat chords: the T2·T3 arc reads **C** and **B**; the T5·T3 arc reads **F** and **B**.

---

## Rim — 10 arcs, 2 printable shapes

The 5/8 base is too wide to split in fifths (347 mm > 256 mm bed), so it's **10 arcs** (≈186 mm each):

- **5 × "T2·T3 arc"** — top seats on chords **C + B**
- **5 × "T5·T3 arc"** — top seats on chords **F + B**

Each arc is a thin wall (= plate rim thickness) standing on a flat foot, with **mitred joint faces**
so neighbors close flush. Every arc has one **3-magnet (tall)** end and one **2-magnet (short)** end;
tall meets tall, short meets short.

---

## Magnets — 1/8 in (3.175 mm) N52 neodymium spheres

- **2 per edge**, free to rotate in their sockets to self-align polarity.
- Total ≈ **1,290 magnets** (≈1,200 in panel edges, 40 arc seats, 50 arc splices).
- Force is not the constraint — a single pair vastly exceeds the model's hoop tension; the sphere shape
  lets each ball find its own polarity.

### The one channel (identical for every magnet)

```
socket Ø3.45  ·  neck Ø3.10 × 0.8  ·  slide Ø3.60 (to perimeter + 3.6 mm)  ·  bevel window Ø1.4
```

- **Socket Ø3.45** — the ball spins here (0.14 mm bigger than the magnet) so it can flip to set polarity.
- **Neck Ø3.10 × 0.8** — a short pinch, 0.075 mm under the ball. The ball is pushed past it once and is
  then captured: gravity can't push it back out. **This is the one fit-critical dimension — see Coupon below.**
- **Slide Ø3.60** — the wide entry channel. It runs from the neck out to the **perimeter** (the inner rim
  wall) and then **3.6 mm further into the pocket** — just enough to drop the ball in and start a tamper rod
  straight. It does not run deep into the pocket.
- **Bevel window Ø1.4** — the socket is sunk **1.577 mm** behind the mating bevel so the bevel truncates it
  to a Ø1.4 opening. The magnet sits **flush** (0.01 mm proud) and kisses the neighbor through the window;
  it can't fall out the window (1.4 < 3.175) or back out the neck.

### How magnets are loaded (post-print, printer OFF)

Drop the ball into the slide from the pocket side, then push it with a small blunt rod (a **tamper**,
~2.5–3 mm) through the neck until it snaps into the socket flush at the window. The slide is the tamper's
guide. Panel edges load **perpendicular to the edge** from the pocket; arc seats load **up from the floor**;
arc splices load from the **inner face**.

### Keys (so wrong edges never mate)

Two magnets per edge at **t = 0.5 ± key**, symmetric about the midpoint, distinct per chord:

| A | B | C | D | E | F |
|---|---|---|---|---|---|
| ±0.14 | ±0.19 | ±0.24 | ±0.29 | ±0.34 | ±0.39 |

→ 21.6 mm apart on A edges, widening to 77.3 mm on F edges.

Splice keys: **3 magnets** stacked up the tall (T2·T3↔T5·T3) joints, **2** up the short
(T5·T3↔T2·T3) joints, ~7.7 mm apart, from 4 mm above the floor to 4 mm below the top.

---

## The coupon — dial in the neck before committing

The neck (Ø3.10) grips a Ø3.175 ball with only **0.075 mm of interference — smaller than a 0.4 mm
nozzle's dimensional repeatability (±0.1–0.15 mm).** So the *exact* neck that captures-and-holds while
still letting the ball spin can't be predicted; it must be measured on your machine.

A **coupon** is a small throwaway test print — not a whole panel. The useful one here is a **neck sweep**:
one small block with the real socket-neck-slide-window channel repeated ~5 times at
**neck = 2.9 / 3.0 / 3.1 / 3.2 / 3.3 mm**, printed in the same **horizontal channel orientation** as a
panel (outer-face-down). Drop a magnet in each; whichever neck snaps the ball past and holds it while it
still spins is your number. Then rebuild every panel/arc with that neck.

Shortcut if you don't want a separate coupon: **print your face test plate at neck 3.10 and use it as both
the coupon and your first real face.** If 3.10 is too tight or too loose once magnets arrive, it's a
one-line change and a reprint, with a real target to aim at.

Even with no magnets on hand yet, the first plate confirms everything that *doesn't* depend on them: flat
release, clean bevel dry-fit, readable labels, brim/first-layer behavior on the thin rim, and crisp slide
openings and windows.

---

## Print settings (Bambu P1S, 256 mm bed, 0.4 mm nozzle, one color at a time)

Standard:

- **Outer-face-down**, brim ON (~5 mm), **supports OFF**, elephant's-foot compensation ~0.15 mm.
- Do **not** auto-orient / "place on face" — parts are already flat and correctly oriented; just Auto-arrange.
- Full face (16 panels + 2 arcs) ≈ 3 plates.

For rounder holes and a crisper neck (the channels print as horizontal holes, whose tops tend to sag):

- **Layer height 0.16 mm** for panels (**0.12 mm** for the coupon) — thinner layers round the horizontal holes.
- **Calibrate flow rate / extrusion multiplier first** — over-extrusion is what closes small holes and tightens the neck.
- **Calibrate pressure advance** — keeps hole edges sharp instead of bulged.
- **Slow the outer wall / small-perimeter speed** (~50–100 mm/s) so the channel walls lay down cleanly.
- If slicing in **OrcaSlicer**, enable **X-Y hole compensation** to counter the typical hole under-sizing
  (Bambu Studio lacks a direct equivalent — lean on flow calibration there).
- The Ø1.4 window will likely print slightly under — that only *improves* retention, so it's fine.

Color scheme (single color at a time):

- **5 greys** = 5 panel shapes (T1 lightest at the vertex clusters → T5 charcoal at the face centers;
  T3-L/R share a tone, magnets enforce chirality).
- **Clear / translucent** reserved for the rim arcs, so the base recedes.

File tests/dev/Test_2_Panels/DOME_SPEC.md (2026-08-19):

# Magnetic Geodesic Dome — Scale Model Spec Sheet

A 3D-printed, magnet-assembled scale model of a geodesic dome (Montreal Biosphère–inspired),
built as a proof-of-concept for an eventual full-size welded structure.

*Rev. after first test print: tapered channel (prints open), show-face-flush orientation (no tilt),
thicker arc walls, bigger/deeper labels. See "First-print revisions" at the end.*

---

## Geometry

| | |
|---|---|
| Solid | Icosahedron |
| Subdivision | **4V (frequency 4)**, **Class I, Method 1** ("alternate") |
| Sphere diameter | **24 in (610 mm)** — radius R = 305 mm |
| Truncation | **5/8** (vertex-up, cut just below the equator at z ≈ −84 mm) |
| Dome height | ≈ 389 mm |
| Base diameter | ≈ 590 mm (a 20-sided zig-zag, amplitude only 7.7 mm) |

The base chord cycle repeats **C · B · F · B** (panels **T2 · T3 · T5 · T3**) five times around.

---

## Panels — 200 total, 6 printable shapes

| Shape | Chords | Edge lengths (mm) | Count |
|---|---|---|---|
| **T1** | A·A·C | 77.2 · 77.2 · 90.0 | 30 |
| **T2** | B·B·C | 89.8 · 89.8 · 90.0 | 35 |
| **T3-L** | B·D·E | 89.8 · 91.1 · 95.4 | 40 |
| **T3-R** | B·D·E | 89.8 · 91.1 · 95.4 | 40 |
| **T4** | E·E·F | 95.4 · 95.4 · 99.1 | 40 |
| **T5** | F·F·F | 99.1 · 99.1 · 99.1 | 15 |

Chord factors → mm (× R = 305): **A 77.2 · B 89.8 · C 90.0 · D 91.1 · E 95.4 · F 99.1**

Each panel: thin central **web 2.2 mm**, thicker **magnet rim 5.2 mm**, edges beveled along the
sphere's radial rays so they close into a sphere. Printed **outer-face-down** for a glossy exterior.

---

## Part labels (debossed on the inner face)

So panels can be sorted and oriented at assembly, each carries ID marks **debossed 0.6 mm into the
inner (pocket) face** — hidden on the finished dome, and facing up during printing so they engrave
cleanly with no supports. The outer show face is untouched.

- **Shape name** (T1 / T2 / T3L / T3R / T4 / T5) centered on the web, upright along the longest edge.
- **Chord letter** (A–F) centered on the rim band beside each edge, so the mating chord is obvious.
- **Arcs** carry their two seat chords: the T2·T3 arc reads **C** and **B**; the T5·T3 arc reads **F** and **B**.

---

## Rim — 10 arcs, 2 printable shapes

The 5/8 base is too wide to split in fifths (347 mm > 256 mm bed), so it's **10 arcs** (≈186 mm each):

- **5 × "T2·T3 arc"** — top seats on chords **C + B**
- **5 × "T5·T3 arc"** — top seats on chords **F + B**

Each arc is a wall standing on a flat foot, with **mitred joint faces** so neighbors close flush. The wall is
**7 mm thick** (thicker than the 5.2 mm panel rim): the panel-to-arc joint angle made a 5.2 mm wall too slim
behind the seat sockets, so they broke through the inner face — the extra material is added on the inner side,
seats stay at the outer bevel so panel mating is unchanged. Every arc has one **3-magnet (tall)** end and one
**2-magnet (short)** end; tall meets tall, short meets short. (Arc seats load vertically and print as clean
holes, so they keep a stepped Ø3.1 throat rather than the taper.)

---

## Magnets — 1/8 in (3.175 mm) N52 neodymium spheres

- **2 per edge**, free to rotate in their sockets to self-align polarity.
- Total ≈ **1,290 magnets** (≈1,200 in panel edges, 40 arc seats, 50 arc splices).
- Force is not the constraint — a single pair vastly exceeds the model's hoop tension; the sphere shape
  lets each ball find its own polarity.

### The one channel (identical for every magnet)

```
Ø1.4 window ← spherical seat → Ø3.45 cylinder → short chamfered throat Ø3.1 → slide Ø3.60 (to perimeter + 3.6 mm)
```

The channel axis is straight (one revolve, so no boolean-junction faces). One axis works because the kiss
direction (out the bevel) and the load direction (in from the pocket) are only ~5° apart on this
shallow-dihedral dome.

- **Spherical seat + Ø1.4 window** — the front of the socket is a **sphere** (Ø3.45) sunk 1.577 mm behind the
  bevel, which the bevel truncates to the Ø1.4 window. Only a sphere seats the ball **concentric and flush**
  (front 0.01 mm proud) so neighbor magnets actually touch. *(A cone was tried and rejected: it seats the ball
  ~0.26 mm recessed → a ~0.5 mm gap between magnets.)*
- **Cylinder socket Ø3.45** — behind the sphere seat, a short cylinder gives the ball room to spin (set
  polarity) and is forgiving of exactly where it settles.
- **Short chamfered throat Ø3.1** — a brief V (chamfer down to Ø3.1, chamfer back up to the slide). The
  chamfers print open (no ledge — the old *stepped* Ø3.10 neck bridged shut on the first print), and because
  the pinch is short (**~0.1 mm of interference, vs the old 0.8 mm neck**) the ball pushes through easily with
  a tamper. Ø3.1 is a hair under the 3.175 ball → **light mechanical capture in ANY orientation** (panels
  horizontal, arc seats vertical), so gravity can't drop a rim magnet. **Final throat TBD by magnet fit test.**
- **Slide Ø3.60** — runs from the throat to the **perimeter** then **3.6 mm into the pocket** — just enough
  to drop the ball in and start a tamper rod straight.

*(Arc seat/splice magnets still use the older sphere-socket retention — they print vertically as clean holes,
so it's fine there; panel and arc sockets can be unified later once the fit is proven.)*

### How magnets are loaded (post-print, printer OFF)

Drop the ball into the slide from the pocket side, then push it with a small blunt rod (a **tamper**,
~2.5–3 mm) through the neck until it snaps into the socket flush at the window. The slide is the tamper's
guide. Panel edges load **perpendicular to the edge** from the pocket; arc seats load **up from the floor**;
arc splices load from the **inner face**.

### Keys (so wrong edges never mate)

Two magnets per edge at **t = 0.5 ± key**, symmetric about the midpoint, distinct per chord:

| A | B | C | D | E | F |
|---|---|---|---|---|---|
| ±0.14 | ±0.19 | ±0.24 | ±0.29 | ±0.34 | ±0.39 |

→ 21.6 mm apart on A edges, widening to 77.3 mm on F edges.

Splice keys: **3 magnets** stacked up the tall (T2·T3↔T5·T3) joints, **2** up the short
(T5·T3↔T2·T3) joints, ~7.7 mm apart, from 4 mm above the floor to 4 mm below the top.

---

## The coupon — dial in the neck before committing

The neck (Ø3.10) grips a Ø3.175 ball with only **0.075 mm of interference — smaller than a 0.4 mm
nozzle's dimensional repeatability (±0.1–0.15 mm).** So the *exact* neck that captures-and-holds while
still letting the ball spin can't be predicted; it must be measured on your machine.

A **coupon** is a small throwaway test print — not a whole panel. The useful one here is a **neck sweep**:
one small block with the real socket-neck-slide-window channel repeated ~5 times at
**neck = 2.9 / 3.0 / 3.1 / 3.2 / 3.3 mm**, printed in the same **horizontal channel orientation** as a
panel (outer-face-down). Drop a magnet in each; whichever neck snaps the ball past and holds it while it
still spins is your number. Then rebuild every panel/arc with that neck.

Shortcut if you don't want a separate coupon: **print your face test plate at neck 3.10 and use it as both
the coupon and your first real face.** If 3.10 is too tight or too loose once magnets arrive, it's a
one-line change and a reprint, with a real target to aim at.

Even with no magnets on hand yet, the first plate confirms everything that *doesn't* depend on them: flat
release, clean bevel dry-fit, readable labels, brim/first-layer behavior on the thin rim, and crisp slide
openings and windows.

---

## Print settings (Bambu P1S, 256 mm bed, 0.4 mm nozzle, one color at a time)

Standard:

- **Outer-face-down**, brim ON (~5 mm), **supports OFF**, elephant's-foot compensation ~0.15 mm.
- Do **not** auto-orient / "place on face" — parts are already flat and correctly oriented; just Auto-arrange.
- Full face (16 panels + 2 arcs) ≈ 3 plates.

For rounder holes and a crisper neck (the channels print as horizontal holes, whose tops tend to sag):

- **Layer height 0.16 mm** for panels (**0.12 mm** for the coupon) — thinner layers round the horizontal holes.
- **Calibrate flow rate / extrusion multiplier first** — over-extrusion is what closes small holes and tightens the neck.
- **Calibrate pressure advance** — keeps hole edges sharp instead of bulged.
- **Slow the outer wall / small-perimeter speed** (~50–100 mm/s) so the channel walls lay down cleanly.
- If slicing in **OrcaSlicer**, enable **X-Y hole compensation** to counter the typical hole under-sizing
  (Bambu Studio lacks a direct equivalent — lean on flow calibration there).
- The Ø1.4 window will likely print slightly under — that only *improves* retention, so it's fine.

Color scheme (single color at a time):

- **5 greys** = 5 panel shapes (T1 lightest at the vertex clusters → T5 charcoal at the face centers;
  T3-L/R share a tone, magnets enforce chirality).
- **Clear / translucent** reserved for the rim arcs, so the base recedes.

---

## First-print revisions (what the test plate taught us)

The first full-face print worked, and revealed four things — all now fixed in the files:

1. **Stepped neck plugged shut.** The horizontal channel's abrupt slide→neck step sagged closed at the neck.
   → **Tapered channel** (Ø3.6 → Ø3.1 cone), which prints open. Bonus: it also removed a stubborn
   non-manifold edge on the symmetric T5.
2. **Show face printed with a tilted patch.** The old flatten aligned to the panel's average plane (PCA),
   tilting the show face ~0.3° so a corner floated ~0.2 mm off the bed and the first layer was skipped there
   (a crisp triangular texture change). → **Orient on the show face itself**, so it lies dead flat (corner
   spread now 0.000 mm).
3. **Arc seat sockets bled through to a slit** on the inner face (only ~0.8 mm of wall behind them).
   → **7 mm arc wall** (2.6 mm backing now). The *splice* openings on the arc inner face are intentional
   (that's how those end magnets load) and stay.
4. **Chord letters a little hard to read.** → **bigger (4.5 mm) and deeper (0.8 mm)**.

Still open, to finalize with real magnets: the exact **throat diameter** (3.1 is the safe capture default;
loosen toward 3.2 only if it's too tight to seat), and confirming the window/throat print cleanly enough that
magnets seat and hold without hand-clearing.

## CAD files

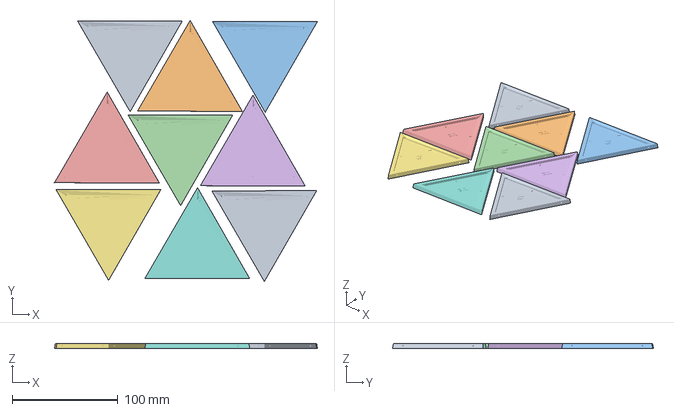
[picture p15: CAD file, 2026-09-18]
3mf/T5_DK_GR_2X.3mf
248.5 x 246.8 x 5.11 mm
T5.stl x 9

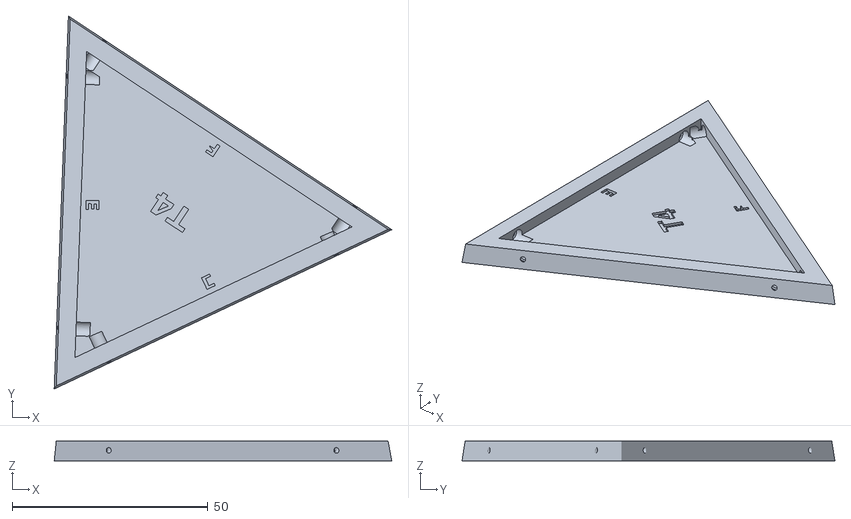
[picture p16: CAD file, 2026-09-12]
stl/T4.stl
86.3 x 95.4 x 5.11

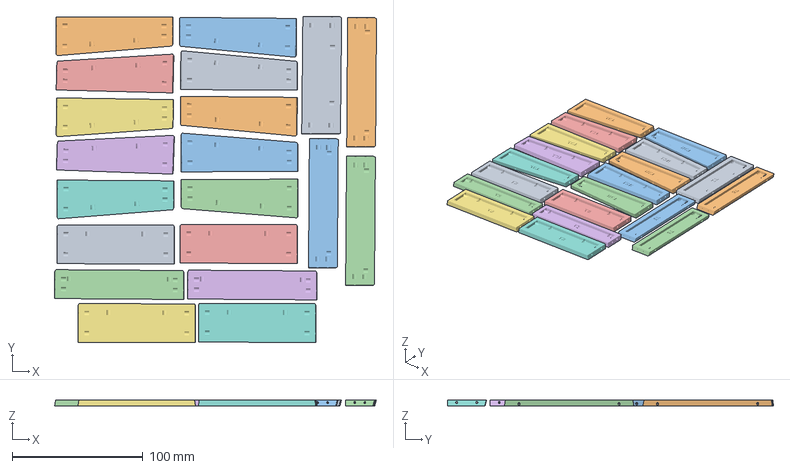
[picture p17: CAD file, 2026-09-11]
tests/3mf/prod_arc_BLK.3mf
246.5 x 250.0 x 4.97 mm
arc_T2.stl x 5
arc_T3L.stl x 5
arc_T3R.stl x 5
arc_T5.stl x 5

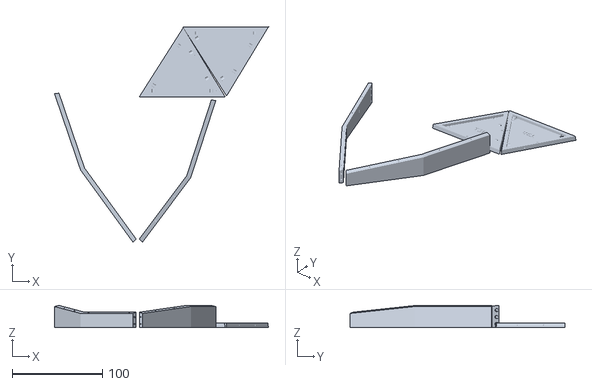
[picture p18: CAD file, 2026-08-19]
tests/dev/Test_1_Panels/FACE_p1.stl
237.7 x 239.3 x 24.7

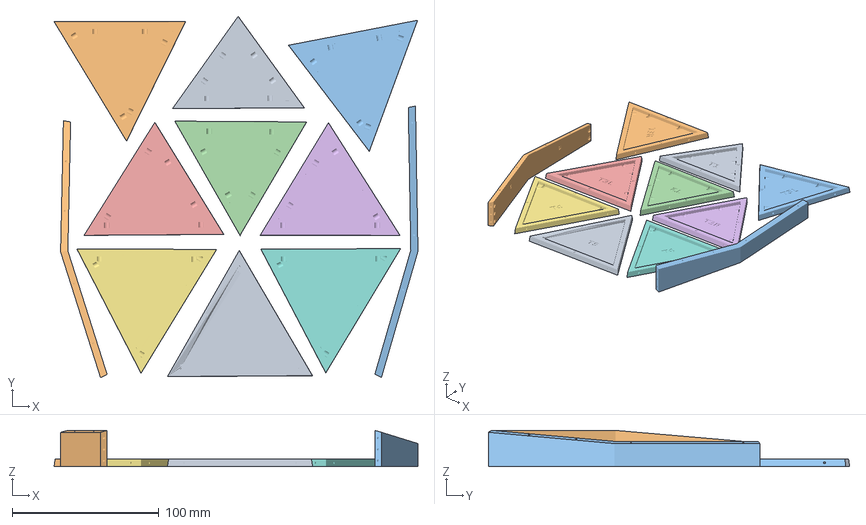
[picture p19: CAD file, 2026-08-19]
tests/dev/Test_1_Panels/Test/Test_4v_plate_1.3mf
248.2 x 246.5 x 24.7 mm
T1.stl
T3R.stl x 2
T3L.stl x 2
T2.stl
T4.stl x 2
T5.stl
arcT2T3.stl
arcT5T3.stl

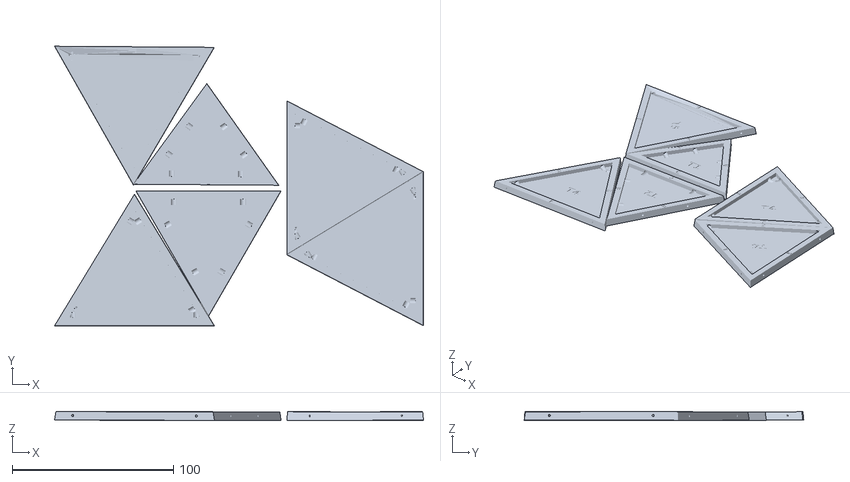
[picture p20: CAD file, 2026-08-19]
tests/dev/Test_2_Panels/FACE_p2.stl
228.6 x 173.2 x 5.53

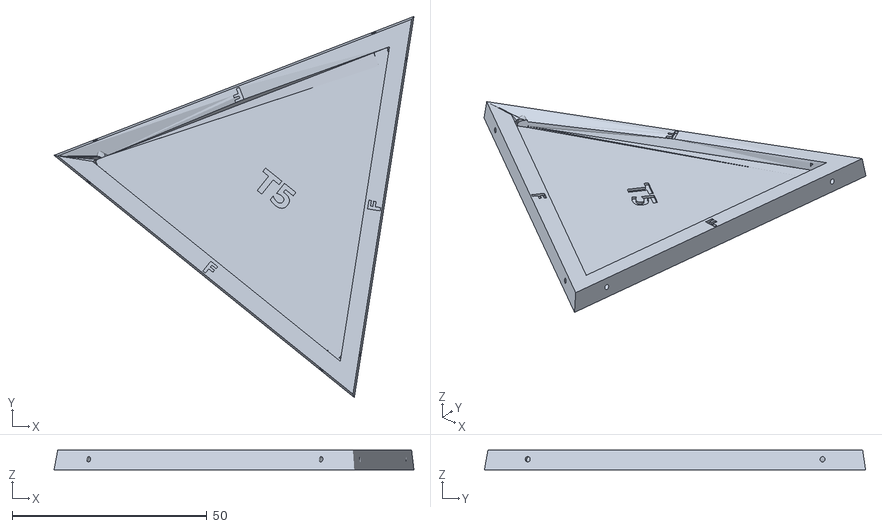
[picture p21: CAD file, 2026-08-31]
tests/dev/Test_2_Panels/singles/T5_v3.stl
92.5 x 97.9 x 5.11

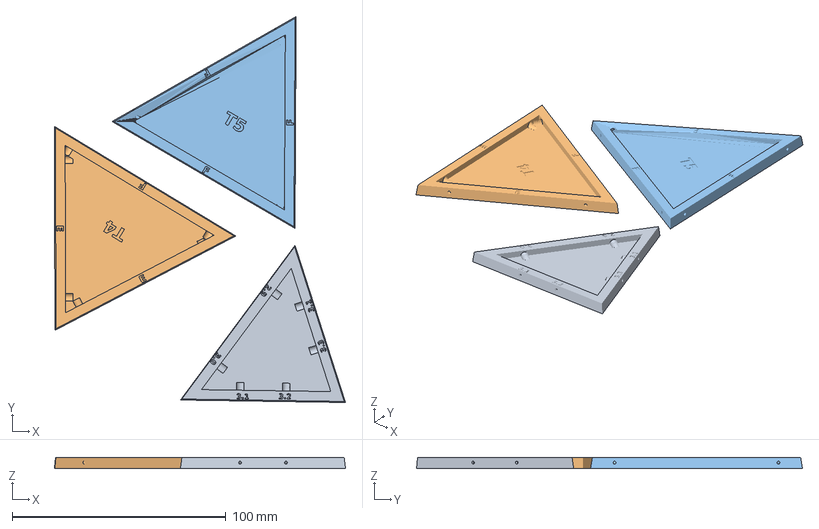
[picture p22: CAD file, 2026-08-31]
tests/dev/Test_2_Panels/Test/Test_4v_plate_3.3mf
136.1 x 180.5 x 5.14 mm
throat_coupon_T1.stl
T4_v3.stl
T5_v3.stl

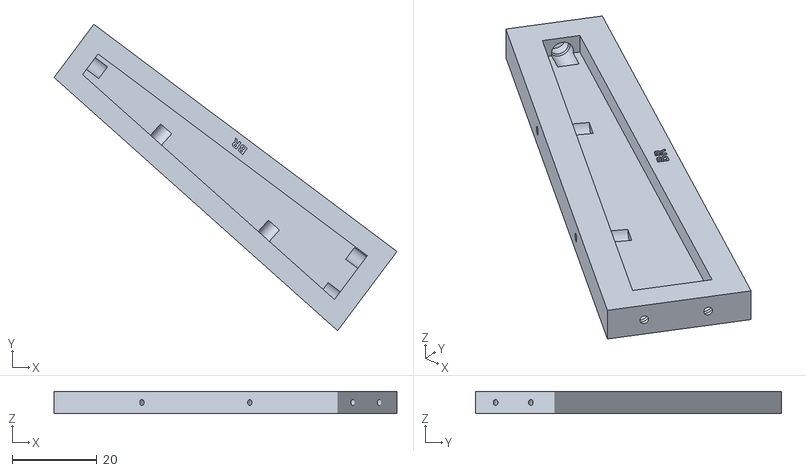
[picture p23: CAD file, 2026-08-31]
tests/dev/Test_3_Arcs/arc_BR_piece.stl
81.0 x 72.4 x 5.20

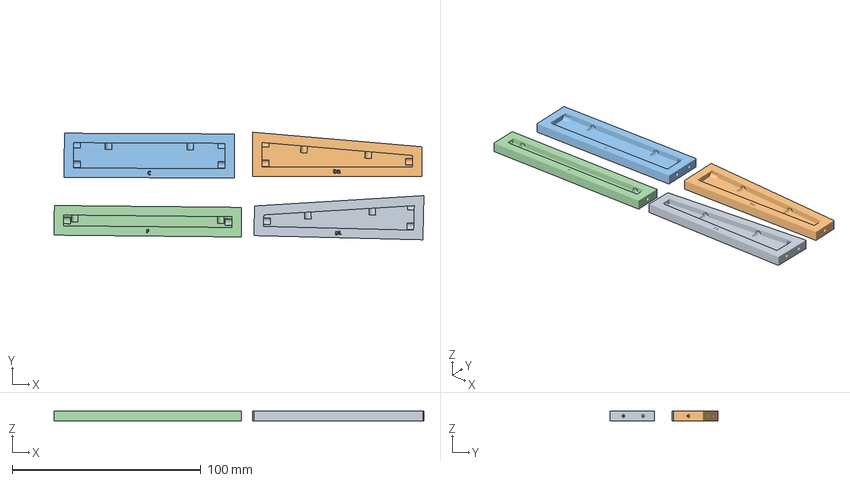
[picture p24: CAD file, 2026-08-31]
tests/dev/Test_3_Arcs/Test/arc_C_F_BL_BR.3mf
195.8 x 57.0 x 5.20 mm
arc_BL_piece.stl
arc_BR_piece.stl
arc_C_piece.stl
arc_F_piece.stl

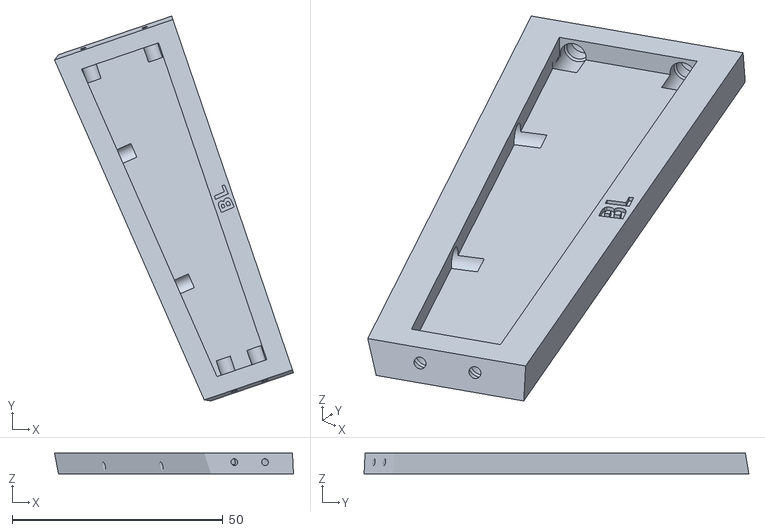
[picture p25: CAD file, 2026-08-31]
tests/dev/Test_4_Arcs/singles/arc_run_BL.stl
56.7 x 91.4 x 4.96

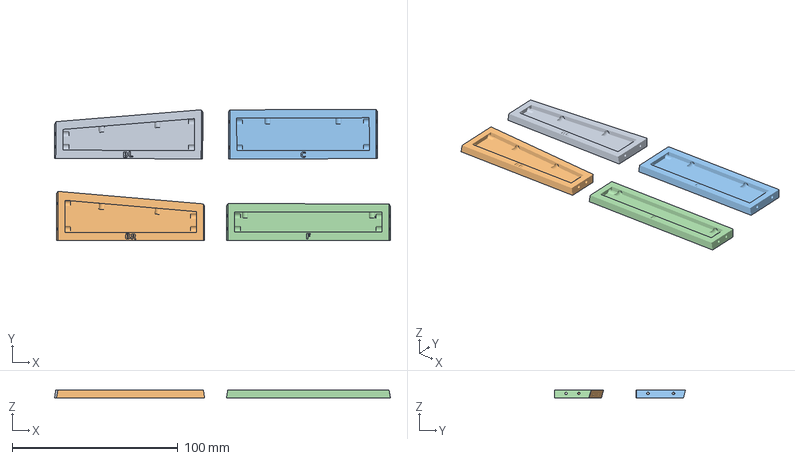
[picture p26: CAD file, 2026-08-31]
tests/dev/Test_4_Arcs/Test/arcs_4.3mf
203.0 x 79.2 x 4.97 mm
arc_run_BL.stl
arc_run_BR.stl
arc_run_C.stl
arc_run_F.stl

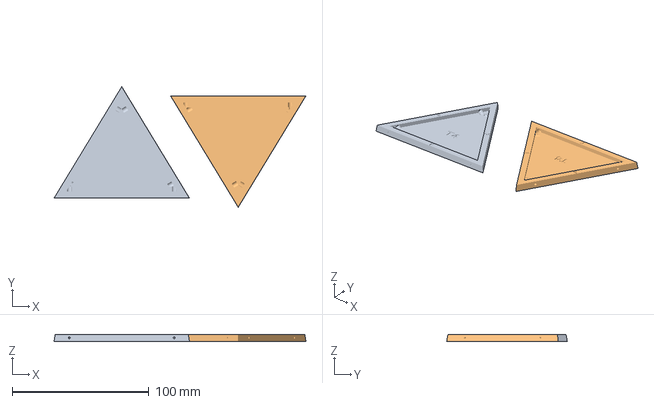
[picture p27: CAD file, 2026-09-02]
tests/dev/Test_5_Arcs/T4_GR.3mf
184.3 x 88.3 x 5.11 mm
T4_t30.stl x 2

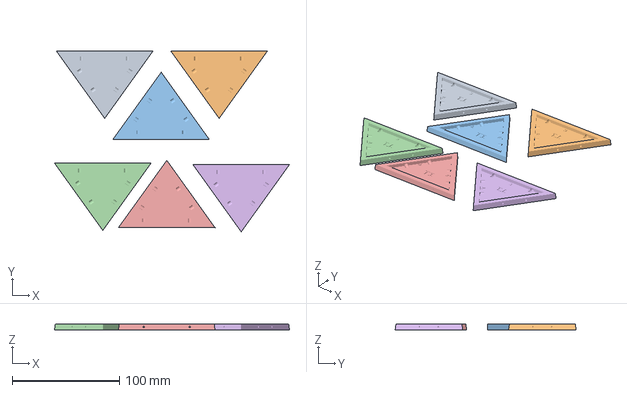
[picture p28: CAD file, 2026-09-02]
tests/dev/Test_6_Arcs_Panels/T1_JADE.3mf
219.1 x 168.5 x 5.14 mm
T1.stl x 6

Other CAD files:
tests/dev/Test_1_Panels/singles/T4.stl
tests/dev/Test_7_Panels/T4_GR.3mf
3mf/T2_LT_GR_3X.3mf
stl/T5.stl
3mf/Arc_BLK_1X.3mf
3mf/T1_JADE_3X.3mf
3mf/T3L_SILVER_4X.3mf
3mf/T3R_SILVER_4X.3mf
3mf/T4_GR_4X.3mf
stl/T1.stl
stl/T2.stl
stl/T3L.stl
stl/T3R.stl
tests/3mf/T1_JADE.3mf
tests/3mf/T2_LT_GR.3mf
tests/3mf/T3L_SILVER.3mf
tests/3mf/T3R_SILVER.3mf
tests/3mf/T4_GR.3mf
tests/3mf/T5_DK_GR.3mf
tests/3mf/arc_BLK.3mf
tests/dev/Test_1_Panels/FACE_p2.stl
tests/dev/Test_1_Panels/FACE_p3.stl
tests/dev/Test_1_Panels/Test/Test_4v_plate_2.3mf
tests/dev/Test_1_Panels/singles/T1.stl
tests/dev/Test_1_Panels/singles/T2.stl
tests/dev/Test_1_Panels/singles/T3L.stl
tests/dev/Test_1_Panels/singles/T3R.stl
tests/dev/Test_1_Panels/singles/T5.stl
tests/dev/Test_1_Panels/singles/arcT2T3.stl
tests/dev/Test_1_Panels/singles/arcT5T3.stl
tests/dev/Test_2_Panels/FACE_p1.stl
tests/dev/Test_2_Panels/FACE_p3.stl
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

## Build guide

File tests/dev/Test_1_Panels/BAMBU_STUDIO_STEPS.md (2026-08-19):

# Getting the dome plates into Bambu Studio (first-timer walkthrough)

Your files: 30 plate STLs (e.g. `T1_plate1.stl`), each already holding several panels laid **flat, outer-face-down**.
On the P1S you print **one color at a time**, so the color is the spool you load — not something you paint in software.

---

## 0. One-time setup (do once)

1. Download **Bambu Studio** from Bambu Lab's site and install it.
2. On first launch it asks for your printer — pick **Bambu Lab P1S**, **0.4 mm nozzle**.
3. Set the filament to **Bambu PLA Basic** (or "Generic PLA") in the filament dropdown, top-right.
4. Connect the printer over your network, or plan to export to the SD card. Either is fine.

---

## Then, per the Bambu workflow — do this one plate at a time

### 1 · Import 3D model
- Drag one plate file (start with **`T1_plate1.stl`**) onto the build plate, or **File → Import → Import STL**.
- It arrives as **one object containing ~12 panels**. Right-click it → **Split → To Objects** (sometimes "Split to Parts") so each panel is separate. This lets the slicer treat them individually and shows you nothing overlaps.
- **Do NOT** hit auto-orient / "Place on face" / auto-arrange — the panels are already correctly flat and outer-face-down, and those tools would re-tilt or shuffle them. (Only if you get an "outside the plate" warning, use **Auto-arrange**, which keeps them flat.)

### 2 · Edit & Colorize
- For single-color printing there's nothing to paint. Just set the top-right filament to the grey this plate uses, so the preview matches — optional, only for your own tracking.
- (Colorize/paint only matters if you later add an AMS for multi-color. Skip it now.)

### 3 · Verify → Slice & Print **test**  (⇄ Tune / Refine loop)
Set these in the left-hand settings, then slice:
- **Layer height** 0.2 mm (or 0.16 for a finer exterior).
- **Brim: ON**, outer, ~5 mm — the thin panels and arc walls need the extra grip.
- **Elephant's-foot compensation** ~0.15 mm (keeps the first layer from bulging over the magnet windows).
- **Supports: OFF** — flat parts need none. If the slicer wants supports, something is tilted; re-check step 1.
- Infill 10–15% (the parts are mostly solid rim anyway).

Click **Slice Plate**, check the preview (no supports, sane time/filament), then **print this one plate**.
When it's done, drop real 1/8″ magnets into a few sockets and confirm: the ball **snaps past the neck and stays**, and still **spins** in the socket. If it's too tight, too loose, or the first layer closed the windows → that's the **Refine parameters** loop: tweak the slicer setting, or tell me and I'll adjust the model's neck/window numbers and regenerate. Re-test until the fit feels right.

### 4 · Add Project Resource files
- Once the settings are dialed, keep them. Use the **plate tabs at the bottom** → **Add Plate**, and import the next STL onto its own plate — or just handle one color group at a time.
- "Project resources" = your models + tuned settings + arrangement, all held together in the project.

### 5 · Pack into a .3mf
- **File → Save Project As → `.3mf`**. That bundles the models, layout, and your slicer settings into one reopenable file.
- Practical tip for 30 plates: save **one .3mf per color** (e.g. `grey1_T1.3mf`), so reprinting a color is one click.

---

## Print order (load spool → print that color's plates)

| Spool | Plates | Files |
|---|---|---|
| grey1 (lightest) | 3 | T1_plate1–3 |
| grey2 | 3 | T2_plate1–3 |
| grey3 (mid) | 8 | T3L_plate1–4, T3R_plate1–4 |
| grey4 | 7 | T4_plate1–7 |
| grey5 (charcoal) | 3 | T5_plate1–3 |
| clear | 6 | arcT2T3_plate1–3, arcT5T3_plate1–3 |

Do **grey1 T1_plate1 as the test print first.** Everything else waits until the magnet fit checks out.

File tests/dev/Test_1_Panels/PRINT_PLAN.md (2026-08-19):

# 5/8 Dome — Print Plan (Bambu P1S, 256 mm bed)

Panels print **outer-face-down** (solid smooth face on the bed, pocket up); brim on; slight elephant's-foot compensation. Arcs print **foot-down**. All panels lie flat at ~5.2 mm.

| Part | Color | Qty | Plates (per plate) | PLA g |
|---|---|---|---|---|
| T1 panel | grey1 (lightest) | 30 | 3 (12+12+6) | 324 |
| T2 panel | grey2 | 35 | 3 (12+12+11) | 456 |
| T3-L panel | grey3 (mid) | 40 | 4 (10+10+10+10) | 546 |
| T3-R panel | grey3 (mid) | 40 | 4 (10+10+10+10) | 546 |
| T4 panel | grey4 | 40 | 7 (6+6+6+6+6+6+4) | 590 |
| T5 panel | grey5 (charcoal) | 15 | 3 (6+6+3) | 231 |
| T2·T3 rim arc | CLEAR/translucent | 5 | 3 (2+2+1) | 115 |
| T5·T3 rim arc | CLEAR/translucent | 5 | 3 (2+2+1) | 99 |
| **TOTAL** | | 200 panels + 10 arcs | **30 plates** | **2907 (~2.9 kg)** |

## By spool
- **grey1 (lightest)**: 3 plates, 324 g
- **grey2**: 3 plates, 456 g
- **grey3 (mid)**: 8 plates, 1092 g
- **grey4**: 7 plates, 590 g
- **grey5 (charcoal)**: 3 plates, 231 g
- **CLEAR/translucent**: 6 plates, 214 g

## Notes
- Panels are pre-oriented flat, outer-face-down; leave them as-is (don't let auto-orient re-tilt them).
- T3-L and T3-R share grey3 but are different shapes — separate plates, same spool.
- Clear arcs are packed 2/plate with room to spare — let Bambu auto-arrange consolidate the 10 arcs onto ~2 plates.
- Filament = solid volume × 1.24 g/cm³; add ~10–20% for brim/purge. Slice one plate for a real time estimate.
- **Before the full run:** print T1_plate1, drop real 1/8" magnets into a few sockets, confirm the Ø1.4 window + 3.1×0.8 neck hold and the ball spins.

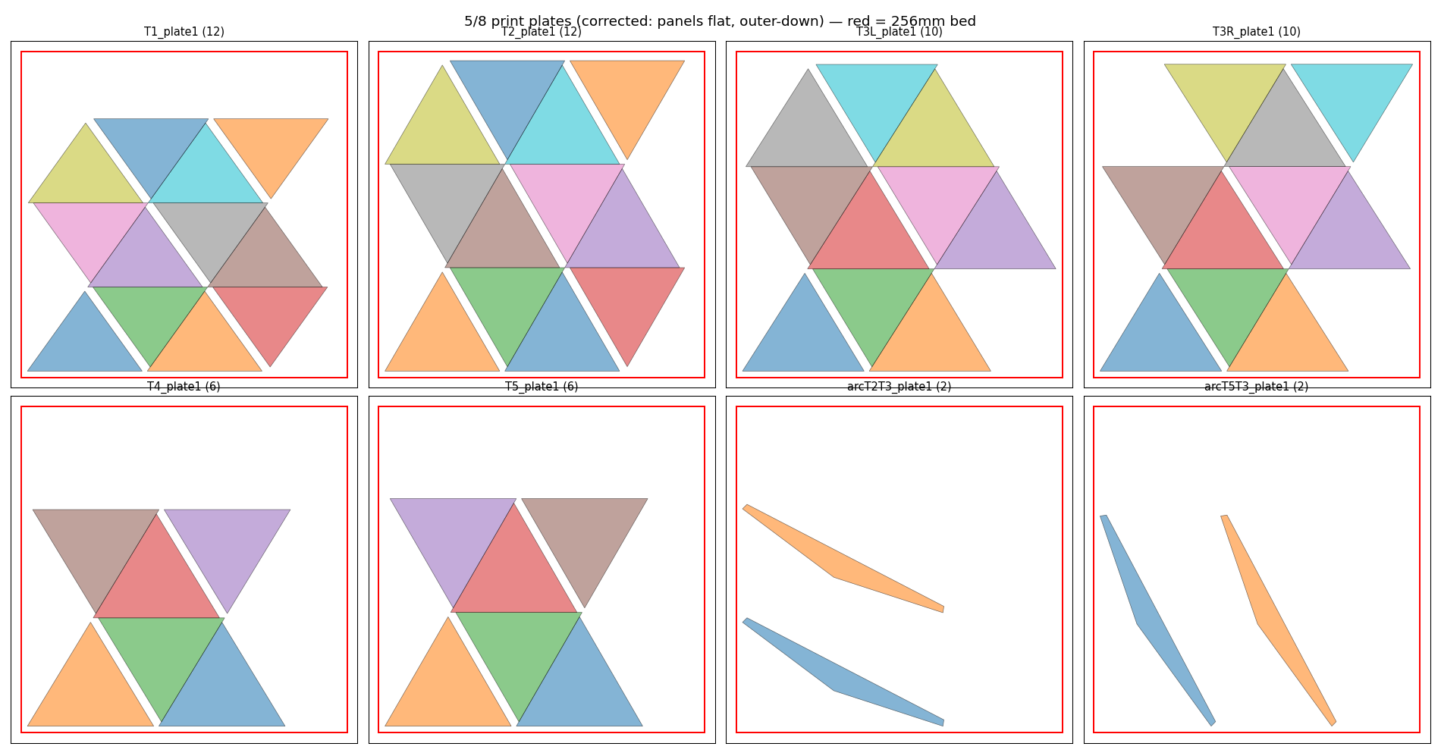
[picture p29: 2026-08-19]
tests/dev/Test_1_Panels/plates58_montage.png

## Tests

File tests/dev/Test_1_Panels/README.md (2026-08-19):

# Full-face kit — now with debossed labels (16 panels + 2 arcs)

Every triangular panel now has ID marks **debossed 0.6 mm into the inner face** (the pocket
side — hidden on the finished dome, facing up while printing so it engraves cleanly, no supports):

- **Shape name** (T1 / T2 / T3L / T3R / T4 / T5) in the center, reading upright along the long edge.
- **Chord letter** (A–F) on the rim band beside each edge, so you can see at a glance which edge
  mates to which. Letters read correctly when you look at the inner face.

The outer (glossy show) face is untouched.

## Contents
- `singles/` — one flat, correctly-oriented STL of each shape (panels outer-face-down, arcs on their
  foot). Import, then **Clone** to the counts below, then press **A** to auto-arrange.
- `FACE_p1..p3.stl` — the whole face pre-packed on 3 plates, ready to slice.

## Counts for one full spherical triangle
3× T1, 3× T2, 3× T3L, 3× T3R, 3× T4, 1× T5, 1× arcT2T3, 1× arcT5T3  (16 panels + 2 arcs)

## Slicer
Brim ON, elephant's-foot ~0.15 mm, supports OFF. Don't auto-orient — parts are already correct.
The deboss is 0.6 mm (3 layers at 0.2 mm), so it stays crisp even with a brim.

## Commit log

2026-08-19 Expand print-settings section; update T4/T5 STLs
    [T4.stl, T5.stl]
2026-08-19 Restore images/ paths; keep expanded print-settings section
2026-08-31 Rebuild rim as 20 panel-family arcs; update README + diagrams
    Claude-Session: https://claude.ai/code/session_01SyxFg51L2kXMge2SpNk7Pp
    [T1.stl, T1_JADE.3mf, T2.stl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]
2026-08-31 Reorganize into dev/ (test iterations) and prod/ (production kit)
    [FACE_p1.stl, FACE_p2.stl, FACE_p3.stl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]
2026-08-31 Fix stale "10 arcs" references left over from rim rebuild
    Sweep all leftover count references to reflect the 20-piece / 4-shape rim.
    Corrects the top-of-README description, the filament table row count,
    per-face count (2 -> 4), and per-piece mass (halved). Totals unchanged.
    Claude-Session: https://claude.ai/code/session_01MpjaTZLYj2igqFms28Hyig
2026-09-01 Correct total magnet count to 1,320 (6 per part × 220 parts)
    Panels contribute 200 × 6 = 1,200; the 20 arc pieces contribute
    20 × 6 = 120. Prior figure (1,290) was left over from the 10-arc rim.
    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
2026-09-02 Refresh prod/ singles + templates; add dev/rims_Test_5
    - prod/singles: replace T1-T5 STLs with current versions; add new
    arc_T2/T3L/T3R/T5.stl (arc pieces named by their upper panel);
    archive prior versions under outdated/ and less outdated/.
    - prod/: move template 3mfs into prod/templates/ (and arc_BLK.3mf).
    - dev/: add rims_Test_5 iteration (T2-T5 _t30 STLs + color 3mfs).
    - images: update 7) net58_labeled.png.
    README paths unchanged (references only the image, which kept its path).
    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
    [T1.stl, T1_JADE.3mf, T1_t30.stl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]
2026-09-02 Add dev/Test_6_arcs_and_panels test bundle; fix stale arc ×10 → ×20
    Test bundle pairs a T1_JADE panel with all four arc shapes (T2/T3L/T3R/T5)
    so the arc redesign can be verified alongside a real panel on one plate.
    prod/arc_BLK.3mf moves into the test folder — the loose top-level copy is
    superseded by prod/templates/arc_BLK.3mf and the per-shape arc singles.
    Also corrects the one remaining stale "Arcs (×10)" cell in the color table.
    Claude-Session: https://claude.ai/code/session_01Lj2uUZhvSVirenjcJpJSCe
    [T1_JADE.3mf, arc_BLK.3mf, arc_T2.stl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]
2026-09-07 Flatten repo: 3mf/ + stl/ at top level, tests/ for archived iterations
    prod/singles/ → stl/ (production single-part STLs)
    prod/templates/ → tests/templates/, replaced by new 3mf/ (T3L+T3R now share
    one T3L_T3R_SILVER.3mf plate since they're both Silver).
    prod/singles/{outdated,less outdated}/ → tests/singles/.
    dev/ → tests/dev/, plus new Test_7_T1_1x iteration.
    README gains a Repository layout section pointing at the new folders.
    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
    [FACE_p1.stl, FACE_p2.stl, FACE_p3.stl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]
2026-09-11 Consolidate generator scripts under scripts/
    geolib.py plus the STL/rim builders (build_final_panels, build_arc_run,
    hoop5, labels) recovered from the prior Claude Desktop session, all now
    alongside net58_full.py so imports resolve without path shims.
    STL filenames are renamed after export (FINAL_T1.stl → T1.stl, etc.);
    builder scripts are left untouched.
    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
2026-09-11 Reorganize repo: renumber tests, refresh 3mf/, ignore Claude outputs
    - tests/dev/ renamed to consistent Test_N_{Panels|Arcs|Arcs_Panels} scheme
    (Test_1_Panels..Test_7_Panels replaces the older facekit_labeled_Test_*,
    Arcs_Test_*, rims_Test_*, Test_6_arcs_and_panels, Test_7_T1_1x names)
    - tests/templates/ → tests/3mf/; the loose superseded prod copy is preserved
    as tests/3mf/prod_arc_BLK.3mf
    - 3mf/ refreshed: new revisions Arc_BLK_1X, T1_JADE_2X+, T5_DK_GR_X land
    alongside T2_LT_GR; the prior 5-file set moved into 3mf/maybe/ pending
    review
    - Test_6_Arcs_Panels and Test_7_Panels hold the latest arc + panel test
    bundles respectively
    - .gitignore: skip "Claude outputs/" (working fo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
    [Arc_BLK_1X.3mf, FACE_p1.stl, FACE_p2.stl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]
2026-09-11 Document _NX plate-count suffix in Repository layout
    The Arc_BLK_1X / T1_JADE_2X+ / T5_DK_GR_X names in 3mf/ encode print
    quantity, not a version. Also notes 3mf/maybe/ as alternate layouts of
    the same STLs.
    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
2026-09-11 Fix stale tests/ paths and note throat-iteration STL archive
    Repository layout section still pointed at the old tests/singles/ and
    tests/templates/ names; both got renamed to tests/stl/ and tests/3mf/
    in the reorg. Also captures that tests/stl/{outdated, less outdated}/
    are the pre-final STLs from the magnet-throat coupon iteration.
    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
2026-09-11 Point STL builders at stl/ with production filenames
    build_final_panels.py now writes stl/{T1,T2,T3L,T3R,T4,T5}.stl (was
    FINAL_*.stl in CWD); build_arc_run.py writes stl/arc_{T2,T3L,T3R,T5}.stl
    (was arc_run_*.stl in CWD). Path is anchored to the script location so
    running from any CWD lands the files in the right place.
    Verified against the current stl/: geometry matches to <1 µm on bounding
    box and <1 mm³ on volume across all 10 parts — small triangle-count
    drift comes from newer manifold3d retriangulation, not from any change
    in shape.
    The arc plate output (arc_run_plate.stl) still lands in CWD — it's a
    convenience/debug 2×2 layout, not a production single, so it's not
    folded into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
2026-09-11 Pin script deps to the sandbox that generated stl/
    Locks the versions Claude Desktop reported for the environment that
    produced the STLs in stl/ on 2025-09-01: numpy 2.4.4, scipy 1.17.1,
    shapely 2.1.2, manifold3d 3.5.2, matplotlib 3.10.9, trimesh 5.0.0
    against Python 3.11.x.
    Under these pins the builder scripts are fully deterministic — two
    back-to-back runs are byte-identical to each other, and every output
    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
2026-09-11 Add reproducible Docker build image; verify by shape equivalence
    New Dockerfile + scripts/docker-entrypoint.sh package the pinned Python
    3.11 environment (numpy 2.4.4, trimesh 5.0.0, manifold3d 3.5.2, etc.)
    that generated stl/. Two modes:
    docker run --rm geodesic-build # verify
    docker run --rm -v "$PWD":/repo … build # regenerate stl/ on host
    `verify` rebuilds every STL inside the container and confirms it matches
    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
2026-09-11 Paste the passing verify output into the README
    Concrete proof for anyone landing on the repo: the docker verify run
    against the current stl/ shows all 10 parts at Δbbox 0.00 µm and Δvol
    0.000 mm³. Explains why the bytes column shows ≠ under Rosetta while
    every part is still geometrically identical.
    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
2026-09-12 Sanitize degenerate/duplicate faces before STL export
    build_final_panels.py and build_arc_run.py now call
    mesh.merge_vertices()
    mesh.update_faces(mesh.nondegenerate_faces())
    mesh.update_faces(mesh.unique_faces())
    before exporting each STL. manifold3d's CSG post-boolean occasionally
    emits triangles where two vertex indices are the same (zero-area
    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
    [T1_JADE_3X.3mf, T2_LT_GR.3mf, T2_LT_GR_3X.3mf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]
2026-09-18 Add MIT LICENSE; ignore 3mf/maybe/; commit re-saved 3mf plates
    - LICENSE: MIT, © 2026 vanetten.
    - .gitignore: adds 3mf/maybe/ so alternate/pending plate layouts stay
    local without shipping in the public repo. The files remain on disk.
    - 3mf/{T2_LT_GR_3X, T4_GR_4X, T5_DK_GR_2X}.3mf: re-saved by Bambu Studio
    (metadata drift only — identity check still shows CLEAN 144×T2 /
    100×T4 / 81×T5 against the current stl/).
    Prep work for open-sourcing the repo.
    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
    [T1_JADE.3mf, T2_LT_GR.3mf, T2_LT_GR_3X.3mf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]
2026-09-24 Add build photos; record post-build status in README
    Hero shot of the finished dome and a partial-build shot in the
    production-sequence section. Throat locked (Ø3.0 panels + arc tops,
    Ø3.1 arc seams — already what the STL builders emit) is now stated
    directly instead of as an open item, and the T3-L / T3-R chord order
    in the panels table now matches the walk order the generator scripts
    use. Two build observations added: ~1/8 retention failures weighted
    toward the Silver panels, and a small removable piece of plastic in
    the T5 channel.
